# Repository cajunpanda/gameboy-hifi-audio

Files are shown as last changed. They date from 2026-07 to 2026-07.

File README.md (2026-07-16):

# GameBoy HiFi Audio

A Bluetooth audio upgrade for the Game Boy Advance. It removes the console's
stock audio amp and replaces the whole audio back end with an ESP32 and an
ES8388 codec. The mod streams game audio to Bluetooth headphones and speakers,
and it also drives the GBA's built-in speaker and wired headphone jack itself,
with onboard EQ, volume, and sound effects.

<p align="center">
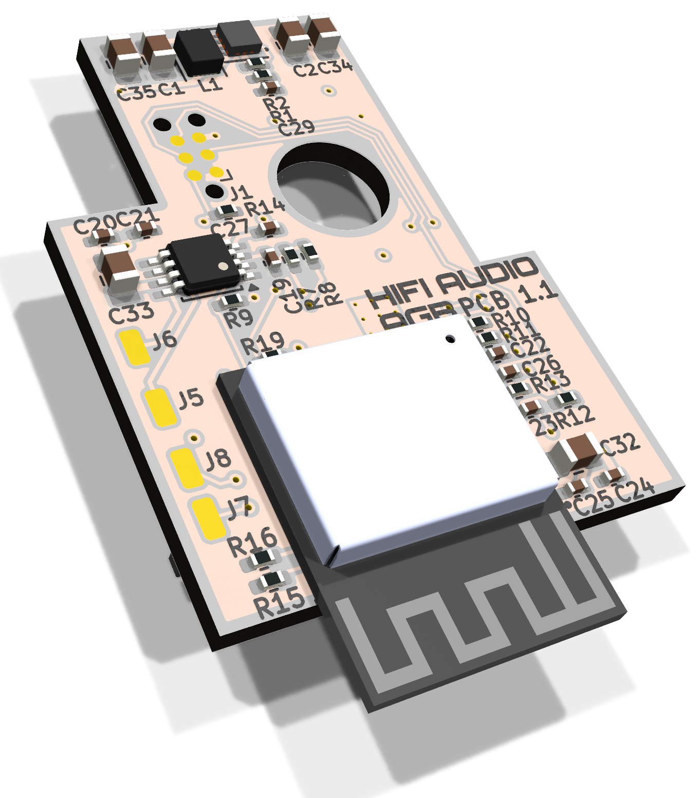
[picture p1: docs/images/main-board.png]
GameBoy HiFi AGB main board
  
  &nbsp;&nbsp;
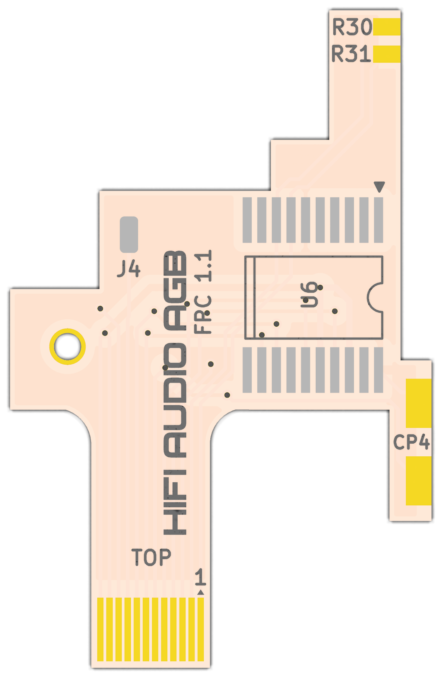
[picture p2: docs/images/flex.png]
GameBoy HiFi AGB flex
  
  <br>
  <sub>AGB main board (left) and flex (right)</sub>
</p>

What you get:

- Bluetooth (A2DP) output to any standard headphones or speaker.
- Wired headphones and the internal speaker, driven by the onboard codec.
- EQ, volume, and sound-effect cues, tunable from a phone or laptop over
  Bluetooth (no app install, it runs in the browser).
- A battery-saver mode that puts the radio and CPU to sleep and passes audio
  through the codec in analog, for long unplugged sessions.
- Firmware updates over Bluetooth.

<p align="center">
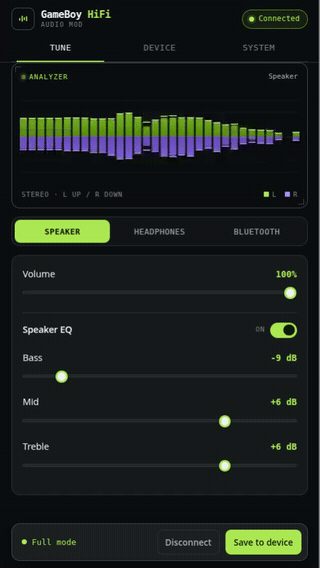
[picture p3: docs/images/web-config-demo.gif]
The web config page: live spectrum and equalizer, tuned in the browser over Bluetooth
  
  <br>
  <sub>The browser config page: a live spectrum and per-output EQ, tuned over Bluetooth with no app to install</sub>
</p>

Prebuilt, pre-assembled kits are coming soon at [cajunpanda.com](https://cajunpanda.com),
for anyone who would rather not source the parts and solder it themselves. Kits will ship
pre-flashed and update over Bluetooth, so they need no programming cable.

I am looking for beta testers interested in trying out the mod. If you want an early kit or
board, reply on the [beta testers discussion](https://github.com/cajunpanda/gameboy-hifi-audio/discussions/1)
or join the [Discord](https://discord.gg/6BNetnK6kC).

This repository currently holds the board for the original Game Boy Advance
(AGB). The firmware is shared across models. Boards for other Game Boy models
will be added under `hardware/` as they are designed.

## Pick your path

This project has three kinds of reader. Start with the doc that matches you.

- **You have a GameBoy HiFi board, or one already in your GBA.**
  [docs/AGB-INSTALL.md](docs/AGB-INSTALL.md) fits the board into a Game Boy Advance, and
  [docs/MANUAL.md](docs/MANUAL.md) covers using it: pairing, the control button,
  the modes, the web config page, and troubleshooting.

- **You want to build the boards yourself.**
  Read [docs/HARDWARE.md](docs/HARDWARE.md): the bill of materials, the KiCad
  boards, fabrication, and assembly. It links on to the install guide once the
  boards are ready.

- **You want to change the firmware.**
  Read [docs/FIRMWARE.md](docs/FIRMWARE.md): the toolchain, build and flash,
  the architecture, the config options, and how the control surfaces work.

## Repository layout

```
firmware/        ESP-IDF firmware (PlatformIO project), shared across boards
hardware/agb/    KiCad projects for the AGB main board and flex (schematic carries the BOM)
web/             Web Bluetooth config page (hosted on GitHub Pages)
tools/           make_clip.py (clip authoring), bringup.py (bench current<->boot correlation)
docs/            the guides above
```

## License

- Firmware and other source code: MIT, see [LICENSE](LICENSE).
- Hardware (schematics, board layouts, footprints): CERN-OHL-P v2, see
  [hardware/LICENSE](hardware/LICENSE).
- Documentation: CC BY 4.0, see [docs/LICENSE](docs/LICENSE).

You can build, modify, sell, and redistribute all of it, including in your own
products, as long as you keep the attribution and the license notices.

## A note on the trademark

Game Boy and Game Boy Advance are trademarks of Nintendo. This is an
independent, unofficial project and is not affiliated with or endorsed by
Nintendo.

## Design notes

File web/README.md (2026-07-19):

# Web config page

A single-file Web Bluetooth control panel for the mod's BLE config server
(`firmware/src/ble_config.c`). It tunes the DSP settings (speaker and Bluetooth
volume, EQ, sound effects), sets the R-button hold timings, plays chimes and
clips, saves to the device, and updates the firmware over the air. It also
converts a dropped audio file to a startup clip in the browser and uploads it.
No app, no WiFi, just Chrome or Edge talking to the ESP32 over Bluetooth.

## Hosting (GitHub Pages)

`.github/workflows/pages.yml` deploys this folder to GitHub Pages on every push
to `main` that touches `web/`. One-time setup: repo Settings, Pages, Source =
GitHub Actions. The page is then served at `https://<user>.github.io/<repo>/`.

Web Bluetooth needs a secure context, which the Pages HTTPS provides. For local
work, serve over localhost (for example `python3 -m http.server` in this folder).
Opening the file directly does not expose `navigator.bluetooth`.

## Use

1. Power the mod. The BLE server advertises as "GameBoy HiFi Setup" with slow
   advertising to keep current low, so discovery can take a couple of seconds.
2. Open the page, click Connect, and pick "GameBoy HiFi Setup".
3. The controls fill in from the device and push live edits back. Save to device
   persists them. Changes made from the UART console show up here through
   notifications.

On Linux, Chrome needs the experimental web platform features flag.

## Firmware update

The Firmware update card pushes a new `firmware.bin` to the device over
Bluetooth. Drop the file, click Flash firmware, and keep the page open until the
device reboots into the new image (a minute or two; audio pauses). The transfer
uses windowed flow control with a host-side crc32 and on-device SHA-256
validation before the boot slot swaps. Older firmware without the OTA
characteristics is detected, and the card disables itself.

The card shows the installed firmware version and slot from the device. The
version comes from `CONFIG_APP_PROJECT_VER` in `firmware/sdkconfig.defaults`.

## Wire format

The settings characteristic is a packed little-endian blob mirroring
`gbhifi_settings_t`. The exact layout is documented in both `web/index.html` and
`firmware/src/ble_config.c` (`SETTINGS_WIRE_LEN`); keep the two in lockstep. The
mode field is read-only status: entering Battery saver duty-cycles the radio to
sleep, so the page cannot reverse it. The R-button hold gesture owns the mode.

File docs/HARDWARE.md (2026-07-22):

# GameBoy HiFi Audio: Hardware Guide

This guide is for building the mod yourself: ordering the boards, sourcing
parts, assembling, and installing it in a Game Boy Advance. The KiCad projects
under `hardware/agb/` are the authoritative reference for the schematic, the
board layout, and the exact net and pin assignments. This document is the
overview.

This is an advanced modification. It requires removing a surface-mount chip from
the GBA mainboard, fine-pitch soldering, and reflow or hot-air work on a QFN
part. If you are not comfortable with that, have it done by someone who is.

## What is on the boards

There are two boards for the AGB:

- **Main board** (`hardware/agb/agb-hifi-audio-pcb`): the ESP32 module, the
  audio codec, the power supply, and the speaker amplifier.
- **Flex** (`hardware/agb/agb-hifi-audio-fpc`): a flexible circuit that solders
  to the GBA's audio-amp footprint and carries power, ground, the audio taps,
  and the control-button signal back to the main board. It folds over once
  during installation.

<p align="center">
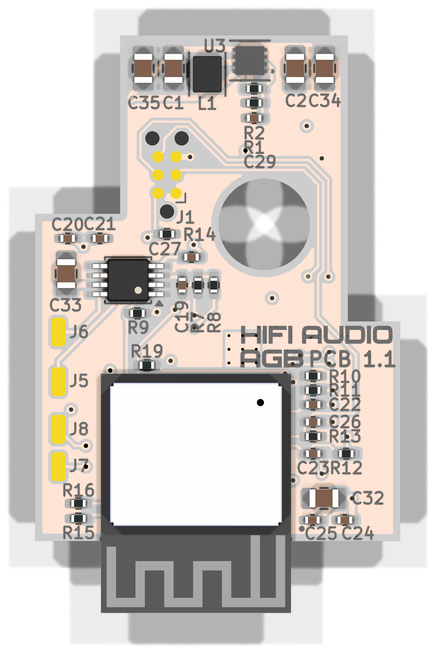
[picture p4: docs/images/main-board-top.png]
AGB main board, top
  
  &nbsp;&nbsp;
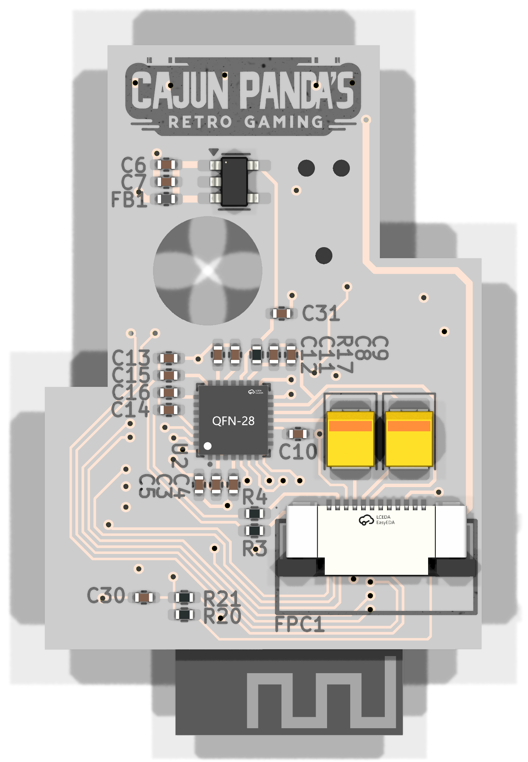
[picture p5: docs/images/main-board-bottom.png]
AGB main board, bottom
  
  <br>
  <sub>Main board, top (left) and bottom (right)</sub>
</p>

## Key parts

The bill of materials lives in the KiCad schematic itself (the source of truth),
where each symbol carries its manufacturer, LCSC, and DigiKey part numbers. Export
it from the [main-board schematic](../hardware/agb/agb-hifi-audio-pcb/). The main
active parts are:

| Ref  | Part | Function |
| ---- | --- | --- |
| U1 | ESP32-PICO-MINI-02-N8R2 | MCU, Bluetooth radio, 8 MB flash |
| U2 | ES8388 | Stereo audio codec: ADC, DAC, headphone amp, analog bypass |
| U3 | TPS61021A | Boost converter, battery to 3.3 V |
| U4 | PAM8302A | Mono Class-D amplifier for the internal speaker |
| U5 | LP5907MFX-3.0 | Low-noise LDO for the codec's analog supply |
| FPC1 | AFC07-S12ECA-00 | 12-pin flat-flex connector for the flex |

The ES8388 is a QFN-28 and is not hand-solderable in the usual sense. Plan on a
stencil and reflow, or hot air. The ESP32 module needs the same treatment: its
pads sit under the module's edge rather than as exposed castellations, so an iron
cannot reach them all. Its pitch is coarser than the codec's, so it is the more
forgiving of the two, but it is still a reflow or hot-air part.

FPC1 is a JLCPCB-stocked part (LCSC C262585). It replaced the Hirose
FH12A-12S-0.5SH, which mates the same flex but uses a different fitting-nail
land pattern, so the Hirose only fits board revisions before 1.1.

### Full bill of materials

Passives are listed by value; the schematic carries the exact manufacturer,
LCSC, and DigiKey part numbers for every line. 26 lines, 60 pieces.

| Ref(s) | Qty | Value / part | Package |
| --- | --- | --- | --- |
| C1, C2, C32–C35 | 6 | 22 µF 25 V | 0805 |
| C3, C6, C8, C10, C11, C20, C24 | 7 | 10 µF | 0402 |
| C4, C7, C9, C21, C25, C26, C30 | 7 | 100 nF | 0402 |
| C5, C15, C16, C19, C27, C31 | 6 | 1 µF | 0402 |
| C12 | 1 | 4.7 µF | 0402 |
| C13, C14 | 2 | 10 nF C0G | 0402 |
| C17, C18 | 2 | 220 µF 6.3 V (tantalum) | EIA-3528 |
| C22, C23 | 2 | 10 nF | 0402 |
| C29 | 1 | 10 pF | 0402 |
| R1 | 1 | 316 kΩ | 0402 |
| R2, R9, R20, R21 | 4 | 100 kΩ | 0402 |
| R3, R4 | 2 | 2.2 kΩ | 0402 |
| R7, R8 | 2 | 15 kΩ | 0402 |
| R10, R13, R14 | 3 | 10 kΩ | 0402 |
| R11, R12 | 2 | 1 kΩ | 0402 |
| R15, R16 | 2 | 4.7 kΩ | 0402 |
| R17 | 1 | 10 Ω | 0402 |
| R19 | 1 | 33 Ω | 0402 |
| L1 | 1 | 0.47 µH (power inductor) | 2.5 × 2.0 mm |
| FB1 | 1 | 600 Ω @ 100 MHz (ferrite bead) | 0402 |
| FPC1 | 1 | AFC07-S12ECA-00 | 12-pin FFC |
| U1 | 1 | ESP32-PICO-MINI-02-N8R2 | SMD module |
| U2 | 1 | ES8388 | QFN-28 (4 × 4 mm) |
| U3 | 1 | TPS61021A | WSON-8 (2 × 2 mm) |
| U4 | 1 | PAM8302A | MSOP-8 |
| U5 | 1 | LP5907MFX-3.0 | SOT-23-5 |

## Ordering the boards

Open the KiCad project (KiCad 10 or newer) and export fabrication data:

1. Run the design rule check and the electrical rule check first.
2. Plot Gerbers and drill files for the main board, and again for the flex.
3. Export the position (centroid) file if you are using an assembly service.

The flex needs special fabrication settings: it is a two-layer polyimide flex
with a stiffener under the connector fingers, and a few intentional edge-plated
lands. Those requirements are written into the flex board as fabrication notes
on the documentation layer, so they travel with the Gerbers. Read them before
you order, and tell the fab house it is a flex, not a rigid board.

JLCPCB and PCBWay both make these. For the main board, their assembly services
can place most of the parts, which saves you the QFN reflow.

## Power

The GBA's switched battery rail (about 2.4 V to 3.2 V) feeds the TPS61021A
boost converter, which produces 3.3 V for the ESP32, the codec's digital side,
and the speaker amp.

The codec's analog supply (AVDD, and HPVDD behind R17) is its own domain: the
3.3 V rail passes through the ferrite (FB1) into U5, an LP5907MFX-3.0 low-noise
LDO (~82 dB PSRR at 1 kHz), which regulates a quiet 3.0 V for the codec's analog
stages. It isolates the codec's DAC, mixer, and headphone amp from the boost
rail, which the Bluetooth radio's wake-up bursts modulate. Bulk caps are spread
across the rail (boost output, boost input, ESP32, speaker amp) for brown-out
margin at low battery.

## The audio source

The GBA CPU does not output a line-level analog signal. Its sound pins (S01 and
S02) are a PWM bitstream. The reconstruction that turned that into analog used
to live inside the amp chip you are removing, so the mod includes its own
reconstruction low-pass filter at the tap. The filtered signal feeds the codec's
line inputs. The codec's input range suits this signal directly, so there is no
preamp.

## Installing the mod

Once the boards are assembled, see [AGB-INSTALL.md](AGB-INSTALL.md) to fit the mod into
a Game Boy Advance: removing the stock parts, attaching the flex, wiring the
speaker, and the first firmware flash.

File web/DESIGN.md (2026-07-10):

# Design

Precision-instrument control panel for the GameBoy HiFi audio mod. A single
self-contained `index.html` (no build, no external assets) served from GitHub
Pages. Dark graphite enclosure, a phosphor-lime "signal" accent (a refined nod
to the DMG screen), violet as the stereo R-channel. Everything technical is
monospace; prose is a humanist sans.

## Theme

- Dark only (`color-scheme: dark`). **Committed** color strategy (one saturated
  signal color carries active states) on an otherwise restrained product surface.
- Metaphor: boutique audio test gear — hairline panels, corner ticks, monospace
  readouts, a live analyzer as the hero.

## Color (OKLCH)

Graphite neutral ramp (cool, hue ~200):

- `--bg` 0.165 · `--bg-2` 0.195 · `--surface` 0.216 · `--surface-2` 0.245 · `--control` 0.275
- `--line` 0.315 · `--line-2` 0.40 (hairlines, borders)
- Ink: `--ink` 0.965 · `--muted` 0.755 · `--faint` 0.605

**Signal — phosphor lime** (the one hot accent: active states, values, primary
actions):

- `--signal` 0.865 0.19 129 · `--signal-2` 0.80 · `--signal-dim` 0.60 · `--signal-soft` (15% signal)
- `--signal-ink` 0.20 0.04 130 — near-black text on lime fills (buttons, toggles, active segment)

**Violet — stereo R-channel + secondary:** `--violet` 0.64 0.19 292 · `--violet-2` 0.72

Semantic: `--warn` 0.82 0.14 82 · `--danger` 0.66 0.19 25. The Connected / OK /
Full-mode states reuse signal lime; Battery saver uses warn amber.

Contrast: body and labels sit at `--muted` / `--ink` on graphite (≥ 4.5:1); lime
and violet are used at high L for values and large text; near-black on lime for
button text.

## Typography

Two families on a **contrast axis (monospace vs humanist)** — no external fonts:

- `--font-sans` = `system-ui` stack — prose, control labels, headings, help text.
- `--font-mono` = `ui-monospace` stack — wordmark, section nav, every numeric
  readout (dB / % / ms), status pill, and equipment micro-labels.

Rationale: monospace *is* the instrument voice, and the mono/sans split carries
the hierarchy, so no display font is needed (preserves the single-file, offline
constraint). Fixed rem scale with tight ratios (product register).

Equipment **micro-labels** (`.label-mono` and the analyzer/output labels): mono,
uppercase, 0.11em tracking, `--faint`. These are diegetic gear labeling (analyzer
header, L/R legend, unit hints) — deliberately *not* the tracked-uppercase
marketing eyebrow anti-pattern.

## Layout — responsive app console

- Content max-width ~46rem. Breakpoint at **820px**.
- **Desktop (≥ 820px):** two-pane grid. A 15rem left **rail** (wordmark +
  `AUDIO MOD`, vertical Tune/Device/System nav with a lime active dot, and a
  pinned footer: mode chip · Save to device · Disconnect) beside a scrolling
  **main** pane led by the analyzer.
- **Mobile (< 820px):** the rail dissolves via `display: contents`. Its top block
  becomes a sticky top bar (wordmark + status pill + underline tab nav); its
  footer becomes a floating **fixed bottom action bar** (mode · Disconnect ·
  Save), with the "Saved ✓" confirmation floating above it.
- Container queries adapt inner grids (e.g. R-button hold timings go 2-up on
  wider main).

## Components

- **Spectrum analyzer (hero):** bordered instrument panel with corner ticks, an
  `ANALYZER` header + live dot + source label, a canvas stereo meter (lime L up /
  violet R down, gradient bars, slow-decay peak caps, faint dB gridlines, a 0 dB
  center line) and an L/R legend. DPR-scaled. Auto-labels and follows the live
  audio source.
- **Output segmented control:** 3-up Speaker / Headphones / Bluetooth; active =
  lime fill + near-black text. Drives which single EQ + volume shows — one
  contextual EQ, not three stacked.
- **Sliders:** thin graphite track, ink thumb ringed in lime, mono value readout
  in lime. EQ bands dim via `:has()` when that EQ is bypassed.
- **Toggles:** graphite off → lime on (near-black knob).
- **Buttons:** primary = solid lime + near-black text; ghost = outline. Flat — no
  gradient, no glow.
- **Status pill / mode chip:** mono; lime when Connected / Full mode, amber for
  Battery saver.
- **Cards:** graphite surface, hairline border, sentence-case titles (no
  eyebrows). Firmware/OTA drop zone, device console (mono), diagnostics/activity
  log.
- **Links:** lime, underlined.

## Motion

- 150–250 ms, state-conveying only. View Transitions crossfade section switches;
  a short staggered entrance plays once on connect.
- The analyzer runs on `requestAnimationFrame` (fast-attack / slow-decay
  smoothing + peak decay).
- `prefers-reduced-motion`: animations and transitions collapse to instant; view
  transitions disabled.

## Constraints

- Single self-contained `index.html`; inline CSS/JS; **no build step, no external
  requests** (CSP-safe, offline-friendly, forkable). Deployed to GitHub Pages via
  `.github/workflows/pages.yml`.
- Web Bluetooth only (Chrome/Edge desktop/Android; iPhone via a Web BLE browser
  app such as Bluefy or BLE-Link). All state comes from the BLE config server;
  no persistence beyond the device.

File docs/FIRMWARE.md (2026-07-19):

# GameBoy HiFi Audio: Firmware Guide

This guide is for building, flashing, and modifying the firmware. The firmware
is shared across all board models.

## Toolchain

The firmware is an ESP-IDF project built through PlatformIO, not through
`idf.py`. You need:

- PlatformIO (the `pio` CLI, or the VS Code extension).
- A Tag-Connect TC2030 serial cable for the first cabled flash. The
  [TC2030-NL-FTDI-C232HD](https://www.tag-connect.com/product/tc2030-nl-ftdi-c232hd-ddhsp-0-dtr-usb-to-tc2030-no-legs-serial-cable)
  carries DTR for auto-reset into the bootloader. Later updates go over Bluetooth.

PlatformIO downloads the ESP-IDF framework and the managed components on the
first build. `firmware/sdkconfig.defaults` is the source of truth for the IDF
configuration; the generated `sdkconfig.prod` is not checked in and is
recreated from the defaults.

## Build, flash, monitor

All firmware commands run from inside `firmware/`:

```sh
cd firmware
pio run                          # build
pio run -t upload                # flash over serial
pio run -t upload -t monitor     # flash and open the serial monitor
pio run -t menuconfig            # IDF menuconfig (edits the generated sdkconfig)
pio device monitor               # serial monitor only (115200 8N1)
```

The build output is `.pio/build/prod/firmware.bin`.

### Recommended: benchmux for iterating

For a build-flash-watch loop, [benchmux](https://github.com/cajunpanda/benchmux) is more
convenient than the raw `pio` commands. It owns the serial port and tees output to a shared
logfile, so it flashes without stopping the monitor, the boot log for the new firmware
streams straight into the log you are already watching, and you can follow that log from any
terminal. It also flashes over BLE. Install it per its README, then from `firmware/`:

```sh
serial_proxy.py monitor --port FTDI &    # own the port, stream to /tmp/serial_proxy.log
serial_proxy.py tail                     # follow the log (from any terminal)
serial_proxy.py flash --env prod         # build + upload without stopping the monitor
serial_proxy.py flash --env prod --fs    # also flash the LittleFS clip image
serial_proxy.py send get                 # inject a console command through the monitor
```

`--fs` flashes the LittleFS clip image that a plain upload skips (see "Partitions and the
clip image"), so a `firmware/data/` change needs no separate esptool step. The commands run
once and exit with a status code, which also makes benchmux a good fit for driving the board
from an editor task or an AI coding agent.

If you change `sdkconfig.defaults`, delete `sdkconfig.prod` to force it to
regenerate. Adding a new `CONFIG_*` symbol in `Kconfig.projbuild` also needs
that delete plus a rebuild, otherwise the build reports the symbol as
undeclared.

`pio run -t upload` flashes only the app. It does not write the LittleFS clip
image, so a change under `firmware/data/` needs a separate filesystem flash (see
"Partitions and the clip image" below).

## Configuration

Project options live in `firmware/src/Kconfig.projbuild` under the
"GameBoy HiFi Audio" menu. Reach them with `pio run -t menuconfig`. The groups:

- **Timeouts and timing**: standby and reconnect timing, the silence detector,
  the R-button hold thresholds, debounce, pairing and wake-hold times, and the
  factory-reset hold.
- **BLE GATT config server**: enables the Web Bluetooth control surface.
- **Speaker DSP defaults**: first-boot seed values for volume, the three EQ
  profiles (speaker, headphone, Bluetooth), and the sound cues. These are only
  the initial seeds; live values persist in NVS and are tuned at runtime.
- **Operating modes**: the default mode at boot, and what happens on a wired
  headphone unplug while in Battery saver.
- Two debug toggles: per-second ADC peak logging, and a one-shot waveform dump
  over UART.

## Partitions and the clip image

`firmware/partitions.csv` defines an 8 MB layout with two OTA app slots (so the
firmware can update itself over Bluetooth), an NVS area for settings and
Bluetooth bonds, and a LittleFS `storage` partition for sound clips.

`pio run -t upload` flashes only the app. It does not flash the LittleFS clip
image, so a plain flash leaves whatever clips were already on the board. The
build bakes `firmware/data/` into a `storage.bin` image (the `src/CMakeLists.txt`
`littlefs_create_partition_image(... FLASH_IN_PROJECT)` line owns the exact
fs-size / block-size / name-max the firmware mounts with). To (re)load the clips,
build and write that image to the `storage` partition offset:

```sh
pio run                                              # bakes .pio/build/prod/storage.bin
esptool.py write_flash 0x420000 .pio/build/prod/storage.bin
```

The `storage` offset (`0x420000`) comes from `partitions.csv`; the generated
`flasher_args.json` lists it too.

The first flash on a fresh board must be a full cabled flash: bootloader,
partition table, app into the first slot, an erased otadata, and the clip image.
After that, updates can go over Bluetooth.

The clips themselves are in the GSFX format. Use `tools/make_clip.py` to author
them: `from-wav` converts a 16-bit WAV to a clip (downmix + optional resample),
or `gen-startup` generates a synth test cue.

The boot chime plays over a muted passthrough (see "Init order"). Which clip it
uses comes from the `startup_mode` setting, whose values are `startup_mode_t` in
`settings.h`:

| mode | clip | notes |
| --- | --- | --- |
| `STARTUP_MODERN` | `startup-modern.gsfx` | the Switch/NSO version, the default |
| `STARTUP_ORIGINAL` | `startup-original.gsfx` | the full original GBA chime |
| `STARTUP_CUSTOM` | `startup-custom.gsfx` | ships with a default; replaced by a web-UI upload |
| `STARTUP_OFF` | none | no clip; the live GBA chime plays through |

`STARTUP_OFF` is not `STARTUP_ORIGINAL`. The codec and amp are still coming up
during the GBA's first ~0.9 s, so the passthrough chime is truncated. That is why
the mod voices its own clip.

All three clips ship in the filesystem image. To change one, author a new
`firmware/data/startup-*.gsfx` and reflash the image (see "Partitions and the
clip image").

The web config page can also replace `startup-custom.gsfx` over BLE. It converts
a dropped audio file to GSFX in the browser, then streams it over the same
OTACTL/OTADATA characteristics a firmware update uses (opcodes `CLIP_BEGIN` /
`CLIP_END`). The device writes to a temp file and renames it into place only once
size, CRC32 and the GSFX header check out, so a dropped link leaves the previous
clip intact. A filesystem reflash restores the bundled default.

## Source layout

```
firmware/src/
  main.c            app_main and the boot/init order
  pinmap.h          every PIN_* macro (the single source of truth for GPIOs)
  es8388.{h,c}      codec driver over I2C: power-up, mode, routing, volume
  i2s_codec.{h,c}   full-duplex I2S master to the codec (MCLK from the ESP32)
  audio_pipeline.{h,c}  ADC capture, int16 conversion, DSP, BT stream, DAC fan-out
  dsp.{h,c}         EQ, volume, and cue mixing for the speaker and BT paths
  settings.{h,c}    runtime-tunable parameters, NVS-backed, the control seam
  sfx.{h,c}         cue player: synth cues and clips streamed from LittleFS
  fs.{h,c}          LittleFS mount for the clip store
  console.{h,c}     UART REPL control surface
  ble_config.{h,c}  BLE GATT config server (drives the web page)
  bt_a2d.{h,c}      Bluedroid wrapper: connect, pair, media, bonds, events
  buttons.{h,c}     debounced ISR for the control button and HP-detect
  app_sm.{h,c}      the state machine, speaker-amp gating, and sleep policy
```

## Architecture

### Audio path

The GBA sound pins (S01/S02) are a PWM bitstream. A reconstruction low-pass
filter on the board turns that into analog, which feeds the codec line inputs.
From there:

```
codec ADC -> ESP32 (I2S RX) -> int16 stereo -> DSP -> split:
  Bluetooth:  stream buffer -> A2DP SBC encoder -> radio
  Local:      codec DAC -> headphone amp (jack) and line out -> speaker amp
```

The pipeline is fixed at 44.1 kHz interleaved stereo, 16-bit. The IDF A2DP
source endpoint hard-codes that SBC format and rejects attempts to change it, so
the sample rate, channel count, and bit depth across the codec, the I2S bus, and
the pipeline all exist to feed that fixed sink. Do not change one without the
others.

### Clocking

The ESP32 is the I2S master. It generates MCLK (from the APLL on GPIO0), BCLK,
and LRCK, and the codec is the slave. One clock domain serves both directions,
so there is no asynchronous resampling.

### Init order

`app_main` is ordered to get **audio out as fast as possible** and to keep the
Bluetooth radio off the Game Boy power-on chime. The mod boots on the GBA's
switched rail, so every power-cycle re-runs this and the chime is the first thing
the user hears.

The sequence: log the wake cause and gate a button wake, boot-mute the speaker
amp, init NVS, bring up the I2S clocks and then the codec over I2C. As soon as the
codec is configured, `app_sm_speaker_early_on()` samples HP-detect and unmutes the
speaker amp (only if no headphones are plugged) — well before the state machine
would otherwise. Then the DSP subsystem comes up: `app_sm_prime_volume()` seeds
the speaker volume from the wheel *before* `dsp_init()` reads it (so a wheel-down
user doesn't get a default-volume blare), and the local EQ profile is seeded from
the sampled HP state. The startup chime is then triggered — `dsp_begin_intro()`
mutes the live passthrough while `sfx_trigger_clip("startup")` plays the mod's own
clean, complete chime (so it isn't doubled with the truncated live GBA chime the
codec misses during boot); this is gated so a future setting can disable it and
let the GBA's own chime through. The audio pipeline and buttons start, and the
pending OTA image is confirmed good.

Only then comes Bluetooth, deliberately last among the heavy loads: `app_main`
waits until `CONFIG_GBHIFI_BT_START_DELAY_MS` after power-on **and** until the
startup chime has fully drained (`sfx_cue_active()`, capped so a wedged cue can't
block BT), parks the speaker amp (`app_sm_amp_radio_quiet()`) across the radio
window, then runs `bt_a2d_init()` (controller + radio) and the BLE config server.
This serialization exists because the radio bring-up is the largest, fastest
current step of the whole boot and on a low battery it can sag the boost rail
below the brownout threshold. Three more pieces of that guard live in firmware:

- `CONFIG_ESP_PHY_RF_CAL_NONE=y` (sdkconfig.defaults) — skips the boot-time
  partial RF calibration TX bursts and runs from NVS-stored cal data. Caveat:
  the first boot after an NVS erase runs a *full* cal (bigger spike), where the
  loop breaker below is the safety net.
- **BR/EDR TX capped at -3 dBm right after controller enable** (bt_a2d.c), so
  inquiry/page bursts never run at the +9 dBm default; the CONNECTED handler
  re-asserts the same level per link.
- **Brownout loop breaker** (main.c): an RTC-noinit magic word is armed around
  the radio bring-up and cleared on success. A boot that starts with reset
  reason BROWNOUT while armed knows the radio killed it: the first strike
  retries after a 2 s settle, two consecutive strikes skip BT for that boot and
  come up LOCAL_ONLY (chime + local audio always play instead of a reboot
  loop). A real power cycle scrambles RTC noinit and re-arms BT. All public
  `bt_a2d_*` calls no-op safely on a BT-skipped boot.

This sequence cold-boots cleanly down to a 2.0 V rail, below any usable 2xAA
level. Finally the factory-reset check, the state machine, and the console start.
The order matters; read the comments in `main.c` before reordering anything.

There is no codec read-back verify pass: the production PCB's series-R + short
MCLK routing keep the I2C config writes clean, so `es8388_init()` alone is enough.

### State machine

`app_sm.c` is the only place that owns device state. Button events, Bluetooth
events, audio silence edges, and timers all fold into one FreeRTOS queue drained
by a single task, so there are no cross-task races on the state. It also owns
the speaker-amp mute policy and the sleep policy.

The audio pipeline and the Bluetooth wrapper are isolated from each other and
from the state machine. They publish events through callbacks, and the state
machine is the only subscriber. Keep that boundary: do not add direct calls
between modules.

### Real-time threading

The real-time audio tasks are pinned to core 1, off the Bluetooth controller
core, or A2DP streaming gets garbled when the controller preempts a shared core.
Tickless idle is off for the same timing reason. There is no per-sample `sinf`
or `expf` in the audio task; the DSP uses lookup tables.

## Settings and control surfaces

`settings.c` is the single source of truth for runtime-tunable parameters
(volumes, the EQ profiles, the cues, the mode preferences, the hold times). It
is thread-safe, NVS-backed, and versioned, with a generation counter so the DSP
recomputes coefficients only when something changes.

Control surfaces only ever call the `settings_*` and `sfx_*` API. They never
touch the audio path. There are two:

- **The UART console** (`console.c`): a REPL for bring-up and tuning.
- **The BLE config server** (`ble_config.c`): the same API exposed over
  Bluetooth for the web page.

### Console commands

```
vol <0-100>          speaker volume
volbt <0-100>        Bluetooth volume
eq on|off [b m t]    speaker EQ
eqhp on|off [b m t]  headphone EQ
eqbt on|off [b m t]  Bluetooth EQ
sfx on|off [level]   cue mixing
chime [name]         play a synth cue
play <name>          play a clip
bt connect|pair      drive BT like the button (page bonds / inquiry-pair)
mode a|b             set operating mode (a = bypass/battery, b = DSP)
unplug stay|b        behavior on HP unplug in Mode A
hold [c p m e]       R-button hold thresholds, ms
wheel on|off         VOL wheel drives volume
ls                   list the clip store
save                 persist settings to NVS
get                  show current settings
```

There are also a few bench helpers (`out1`, `out2`, `outvol`, `codecmode`,
`hp`, `sleep`) for hardware bring-up.

## Web config page

`web/index.html` is a single static page that talks to the BLE config server
over Web Bluetooth. There is no build step and no backend. It is published to
GitHub Pages by `.github/workflows/pages.yml` on any push that touches `web/`.
Web Bluetooth needs a secure context, which the Pages HTTPS provides. The page
reads and writes the settings, uploads clips, and pushes firmware updates.

The System tab mirrors the UART REPL: it streams the device log and takes the
same console commands (`help`, `get`, `batt`, `nr`, ...), so you can watch and
poke a running board over BLE with no cable.

<p align="center">
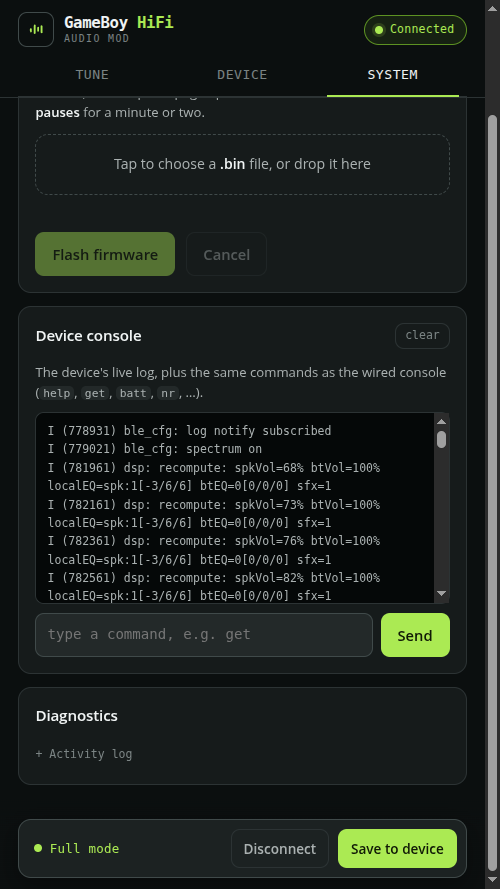
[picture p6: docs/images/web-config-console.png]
The System tab device console: live log and command input over BLE
  
  <br>
  <sub>The System tab's device console: the live log and the same commands as the wired console, over Bluetooth.</sub>
</p>

## OTA updates

The firmware can update itself over Bluetooth. The web page pushes a new
`firmware.bin` to the BLE OTA characteristics; the device writes it to the
inactive app slot, verifies it, swaps the boot slot, and reboots. If a fresh
image fails to finish booting, the bootloader rolls back to the previous slot.
The running image confirms itself good only after init completes without a
panic.

## Board targets

The build targets the ESP32-PICO-MINI-02-N8R2 module (8 MB flash) on the
production board. `pinmap.h` holds every GPIO assignment and is the single source
of truth for pins; the flash size and partition table are set in
`sdkconfig.defaults` and `partitions.csv`. There is one PlatformIO env, `prod`,
so the build output is always `.pio/build/prod/firmware.bin`.

To bring the firmware up on a different ESP32 module (for example a dev board on
the bench), add a PlatformIO env and adjust the GPIO values in `pinmap.h`, which
is the only file the pin map lives in.

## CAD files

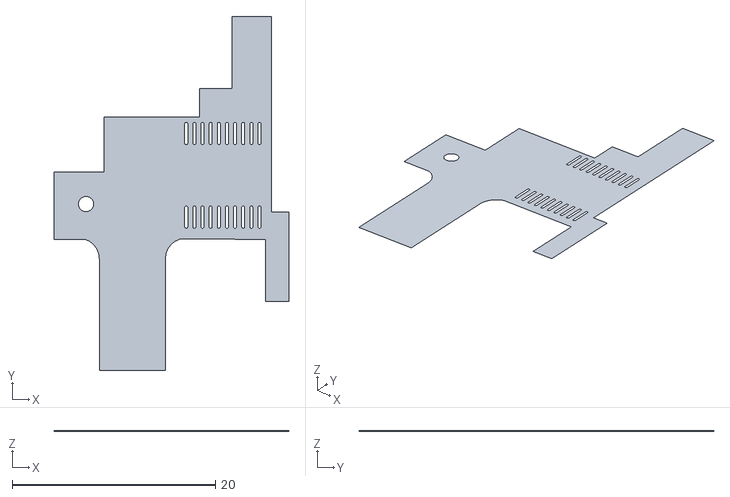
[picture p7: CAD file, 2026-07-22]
hardware/agb/agb-hifi-audio-fpc/agb-hifi-audio-fpc.stl
23.1 x 34.8 x 0.025

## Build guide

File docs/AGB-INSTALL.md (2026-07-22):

# GameBoy HiFi Audio: AGB Installation Guide

This guide covers fitting a GameBoy HiFi board into a Game Boy Advance: removing
the stock parts, soldering on the flex, wiring the speaker, and the first
firmware flash. You need an assembled main board and flex, either from a kit or
built and assembled per [HARDWARE.md](HARDWARE.md).

This is an advanced modification. It involves removing surface-mount parts from
the GBA mainboard and fine-pitch soldering. If you are not comfortable with that,
have it done by someone who is. The changes are permanent: the mod becomes the
console's audio system.

## Video walkthrough

A video of the flex install, start to finish. Watch it before you begin, then
follow the written steps below as you work.

<p align="center">
  <a href="https://youtu.be/mPUGNb_kJ9I">
    Watch: Game Boy Advance HiFi Audio Mod Flex Install
  </a>
</p>

## What you need

- An assembled main board and flex.
- A hot-air station (recommended), or a low-melt desoldering alloy such as
  Chipquik, for lifting U6 and CP4 cleanly.
- A fine-tip soldering iron, flux, and fine solder.
- A Tag-Connect TC2030 serial cable for the first flash, only if you assembled
  the board yourself (see First firmware flash below). Prebuilt kits ship
  pre-flashed and need no cable.
- GBA opening tools (a tri-wing driver for the shell).

## Remove the stock parts

Open the GBA and take out the mainboard. Then remove these parts from it:

- U6, the stock audio amplifier.
- CP4, the coupling caps.
- R30 and R31.
- The speaker.

Use hot air to lift U6 and CP4. If you do not have hot air, flood their pins with
a low-melt alloy (Chipquik or similar) and lift them with the iron. Work
carefully: the flex solders back onto these same footprints, so keep the pads
clean and intact. R30, R31, and the speaker come off with a regular iron.

<!-- photo: U6, CP4, R30, R31, and the speaker removed -->

## Solder on the flex

The flex solders to the freed footprints: U6, CP4, R30, R31, and the speaker
pads. That is how the mod picks up power, ground, the audio taps, the headphone
sleeve return, and the R-button net, and it anchors the flex at the speaker
holes.

Solder the flex exactly per its silkscreen and the KiCad flex project. Follow
that pad mapping, not a generic pinout.

### Tapping the CPU audio (two ways)

The two audio signals (the CPU sound pins S0 and S1) can reach the flex by either
route. Pick whichever you find easier; the result is electrically the same.

- **At the R30 / R31 pads (default).** The flex lands solder directly onto the
  R30 and R31 footprints. These are small pads right at the flex edge, so this is
  the fiddliest joint of the whole install.
- **Through the U6 footprint (alternative).** Bridge across each of the R30 and
  R31 footprints with a short length of fine wire, so the audio passes straight
  through to the U6 footprint. The flex then picks S0 and S1 up at the U6 pads
  (where it already solders), and nothing has to land on the tiny R30 / R31 flex
  lands.

If an S0 or S1 pad lifts or is damaged while you remove the stock parts, bridge
from it to the nearby S0 / S1 via instead. It is the same net, so the tap still
works.

<!-- photo: flex soldered onto the footprints -->

## Connect the boards and the speaker

1. Connect the flex to the main board through the flat-flex connector.
2. Reattach the GBA's own speaker — the one you removed from the mainboard — to
   the mod PCB's `SPK+` / `SPK-` pads, not back to the GBA mainboard. The mod's
   own amplifier drives it.
3. Fold the flex as designed and secure the main board inside the shell.

<!-- photo: flex connected, speaker wired, board secured -->

## First firmware flash

Prebuilt kits ship pre-flashed. If you bought one, skip this step and update over
Bluetooth from the web config page.

A board you assembled yourself has no firmware. Flash it once through the board's
Tag-Connect serial port, then later updates go over Bluetooth. The recommended
cable is the [Tag-Connect TC2030-NL-FTDI-C232HD](https://www.tag-connect.com/product/tc2030-nl-ftdi-c232hd-ddhsp-0-dtr-usb-to-tc2030-no-legs-serial-cable),
which carries the DTR line so the flasher can reset the board into the bootloader
on its own.

See [FIRMWARE.md](FIRMWARE.md) for the build and flash steps.

## After installation

Reassemble the console and power it on. The mod runs off the GBA's battery rail,
so it starts with the console. See [MANUAL.md](MANUAL.md) for pairing, the
control button, and the operating modes.

## Cautions

- Removing U6 and CP4 is permanent. The mod becomes the GBA's audio system.
- Desolder U6 and CP4 with hot air or a low-melt alloy so you do not lift their
  pads; the flex reuses those footprints.

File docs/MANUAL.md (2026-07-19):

# GameBoy HiFi Audio: User Manual

This guide is for using a Game Boy Advance that has the mod installed. If the mod
is not installed yet, see [AGB-INSTALL.md](AGB-INSTALL.md) first. To build the boards
yourself, see [HARDWARE.md](HARDWARE.md).

## What it does

The mod replaces the GBA's audio amplifier with a small board built around an
ESP32 and an audio codec. Once it is installed:

- Game audio streams to Bluetooth headphones or a Bluetooth speaker.
- The GBA's own speaker and headphone jack still work, and they sound better,
  because the board runs the audio through an equalizer and a proper headphone
  amp.
- You can adjust the sound from a phone or laptop over Bluetooth, in the
  browser, with no app to install.

The board is powered from the GBA's battery rail, so it turns on and off with
the console. There is no separate switch.

## The control button

There is one control: the right shoulder button (R). It does double duty. In
games it works as the normal R button, and a quick tap never triggers anything
on the mod. To control the mod you press and hold it.

While you hold R, the device plays a short chime each time you cross a step.
Let go on the step you want:

- Hold about 3 seconds (one chime): connect to your saved headphones.
- Hold about 6 seconds (second chime): enter pairing mode for a new device.
- Hold about 9 seconds (third chime): switch between Full mode and Battery
  saver.

If you hold past a step you do not want, just keep holding to the next one. If
you let go before the first chime, nothing happens.

These hold times can be changed from the web config page if the defaults do not
suit you.

## Pairing your first headphones

1. Turn on the GBA.
2. Put your Bluetooth headphones or speaker into their own pairing mode.
3. Hold R until you hear the second chime (about 6 seconds), then let go. The
   mod is now searching.
4. When it finds your headphones it connects and plays a confirmation chime.

The mod remembers what it paired with, but it does not turn Bluetooth on by
itself. When you turn the GBA on it starts up quietly on the speaker and wired
jack and waits for you. To connect your saved headphones, hold R until the first
chime (about 3 seconds) and let go; it reconnects and plays a confirmation
chime. You only use pairing (the second chime) when you want to add a new
device.

If you have paired more than one device, the first chime tries the most recently
used one first, then cycles through the others.

Once you are connected, a brief dropout fixes itself. If the headphones go out
of range or you turn them off and on, the mod reconnects on its own. It only
gives up, and waits for you to hold R again, if it cannot get them back after a
short while.

If you prefer the mod to reconnect to your saved headphones automatically the
moment you power on, that is available as a saved option. It is off by default so
the radio stays quiet until you ask for it.

## Wired headphones and the speaker

Plug headphones into the GBA's headphone jack and the internal speaker mutes
automatically, the same as a stock console. Unplug them and the speaker comes
back. The board drives the wired jack directly, so wired headphones work even
when nothing is paired over Bluetooth.

## Volume

Use the GBA's volume wheel as usual. It sets the volume for the speaker and the
wired jack. Bluetooth headphones have their own volume control; use that for
Bluetooth listening.

## Full mode and Battery saver

There are two operating modes.

- **Full mode** is the default. It runs the equalizer and sound effects, and it
  streams to Bluetooth. This is the mode you want most of the time.
- **Battery saver** passes the audio straight through in analog and puts the
  processor and radio to sleep between adjustments. It plays through the speaker
  and wired headphones only. The equalizer, sound effects, and Bluetooth
  streaming are paused while it is on. Use it for long sessions when you are
  listening on the speaker or wired headphones and want the most battery life.

Switch between them by holding R to the third chime (about 9 seconds) and
letting go. This works at any time, including while the mod is searching for
headphones: switching to Battery saver stops the search right away and does not
make you wait. In Battery saver there is no chime menu, so to leave it just hold
R for about 9 seconds; the equalizer audio coming back and a chime tell you it
switched.

## Battery life

The mod runs off the GBA's battery rail, so it adds to the console's draw. The
current column below is the extra draw the mod puts on the battery, measured at
the battery terminals; it shifts a little with pack voltage. The runtimes are
rough figures on a fresh pair of AA alkaline cells, listening on the speaker.

| What you are doing | Extra current from the mod | Runtime |
| --- | --- | --- |
| Full mode, local speaker/headphones | ~80 mA | ~13 hours |
| Battery saver, local speaker/headphones | ~30 mA | ~14 hours |
| Bluetooth streaming | ~200 mA | ~9 hours |

Bluetooth is by far the heaviest mode, because the radio draws current in bursts;
if you are not using it, Full mode on the speaker or wired jack lasts much longer,
and Battery saver stretches it a little further still.

These figures are for a stock GBA. If your console has a backlit **IPS screen
mod**, the backlight draws more than the audio mod does, and it roughly halves
every number above (expect about 5 hours of Bluetooth streaming). Turning the
screen brightness down is the most effective way to get that time back.

## The web config page

The config page runs in your browser and talks to the mod over Bluetooth, so it
works from a phone or a laptop with no install. It needs a browser that
supports Web Bluetooth (Chrome or Edge on Android, Windows, macOS, or Linux;
Web Bluetooth is not available in Safari or on iOS).

Open the page:

```
https://cajunpanda.github.io/gameboy-hifi-audio/
```

Then:

1. Turn on the GBA so the mod is running.
2. Click Connect and pick **GameBoy HiFi Setup** from the list.
3. The controls fill in with the current settings. Changes apply live as you
   move them.
4. Click Save to device to keep the changes after a power cycle.

<p align="center">
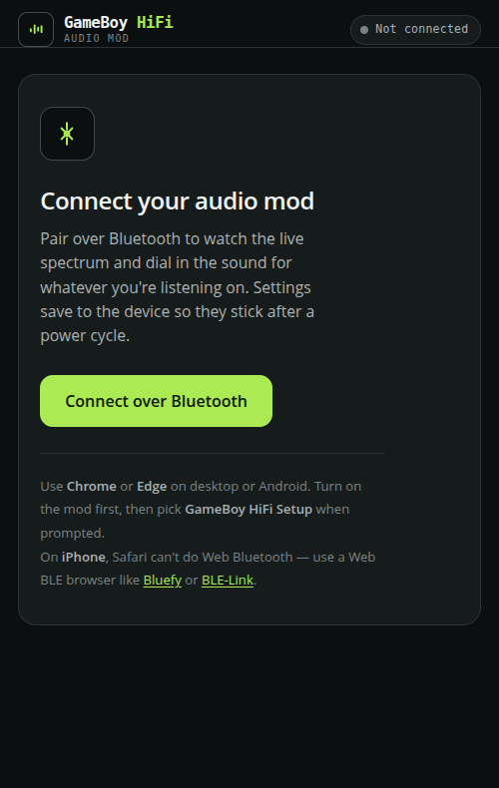
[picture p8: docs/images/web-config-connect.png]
The connect screen
  
  &nbsp;&nbsp;
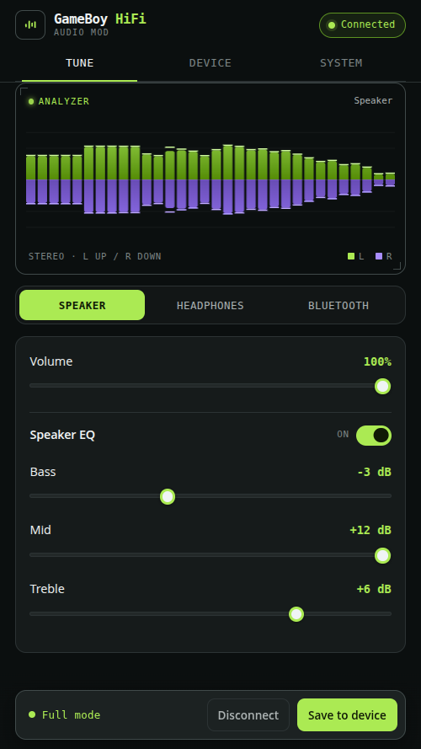
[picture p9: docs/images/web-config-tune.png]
The Tune tab, with a live spectrum and the speaker equalizer
  
  <br>
  <sub>Connect over Bluetooth (left). Once paired, the Tune tab shows a live spectrum and the equalizer (right).</sub>
</p>

The equalizer updates as you drag it, so each change is audible right away:

<p align="center">
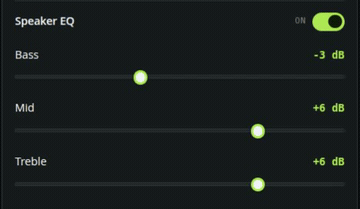
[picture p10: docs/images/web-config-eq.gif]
Dragging the bass, mid, and treble sliders
  
  <br>
  <sub>Bass, mid, and treble, each adjustable live.</sub>
</p>

From the page you can set:

- Speaker volume and Bluetooth volume.
- Equalizer (bass, mid, treble) for the speaker, for wired headphones, and for
  Bluetooth, each on its own.
- Sound effect cues and their level.
- The startup sound: the modern Switch version, the original Game Boy Advance
  chime, your own, or off. Off lets the console's own chime through, which
  starts a moment late because the mod is still waking up.
- Your own startup sound: drop in an MP3, M4A, WAV, OGG or FLAC and the page
  converts the first 4 seconds and sends it over Bluetooth.
- The R-button hold times.
- Firmware updates: push a new firmware file to the mod over Bluetooth. Keep
  the page open until it reboots. Audio pauses for a minute or two during the
  update.

<p align="center">
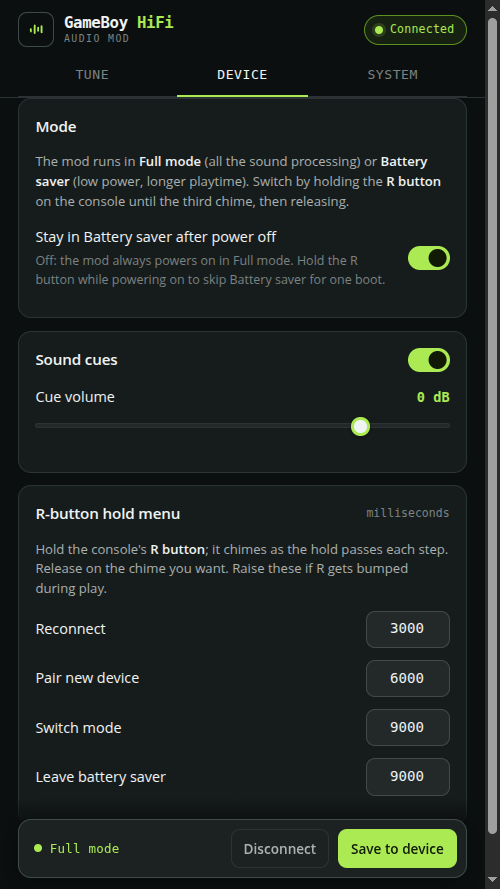
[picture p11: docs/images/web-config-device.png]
The Device tab: modes, sound cues, and R-button hold times
  
  &nbsp;&nbsp;
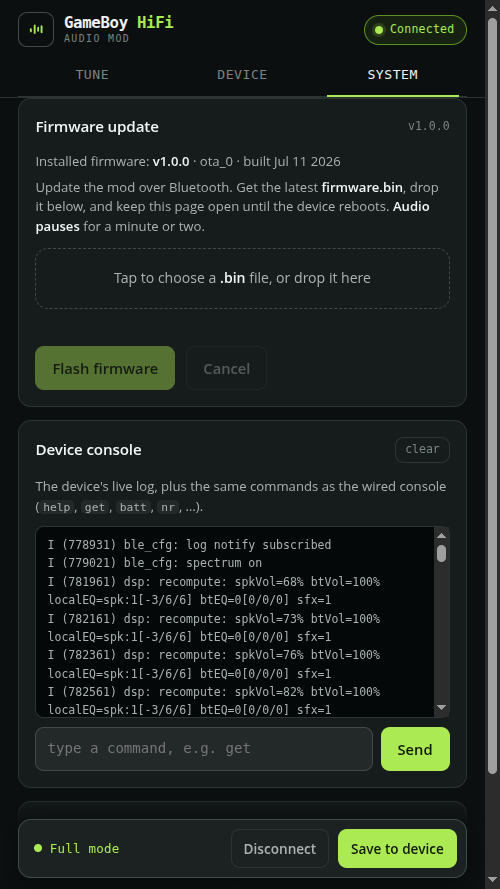
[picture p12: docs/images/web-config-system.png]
The System tab: firmware updates and the device console
  
  <br>
  <sub>Device tab: modes, sound cues, and the R-button hold times (left). System tab: firmware updates (right).</sub>
</p>

## Factory reset

To erase all paired devices, hold R while you turn the GBA on and keep holding
for about 10 seconds. The next time you pair, the device list starts fresh.

## Troubleshooting

**It will not connect to my headphones.**
Put the headphones in pairing mode first, then hold R to the second chime to
search. If it still fails, do a factory reset and pair again.

**It does not reconnect by itself when I turn the GBA on.**
That is normal. The mod waits for you so the radio stays quiet until you want it.
Hold R to the first chime (about 3 seconds) to reconnect your saved headphones.
If you would rather it reconnect automatically at power-on, that can be turned on
as a saved option.

**No sound from Bluetooth.**
Check that you are in Full mode, not Battery saver. Battery saver does not
stream over Bluetooth. Hold R to the third chime to switch.

**No sound from the speaker.**
Make sure nothing is plugged into the headphone jack. The speaker mutes
whenever a plug is detected.

**The web page does not see the device.**
Use Chrome or Edge. Make sure the GBA is on. The mod advertises as
"GameBoy HiFi Setup". If a previous browser tab is still connected, close it
first; only one connection at a time is allowed.

**It paired but keeps dropping.**
Weak battery can cause dropouts because the radio draws current in bursts. Try
fresh or freshly charged batteries.

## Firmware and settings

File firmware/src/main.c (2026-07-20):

#include <inttypes.h>

#include "freertos/FreeRTOS.h"
#include "freertos/task.h"
#include "esp_attr.h"
#include "driver/gpio.h"
#include "driver/rtc_io.h"
#include "esp_app_desc.h"
#include "esp_err.h"
#include "esp_log.h"
#include "esp_ota_ops.h"
#include "esp_sleep.h"
#include "esp_timer.h"
#include "esp_system.h"
#include "nvs_flash.h"

#include "sdkconfig.h"

#include "app_sm.h"
#include "audio_pipeline.h"
#include "ble_config.h"
#include "bt_a2d.h"
#include "buttons.h"
#include "console.h"
#include "dsp.h"
#include "es8388.h"
#include "fs.h"
#include "i2s_codec.h"
#include "pinmap.h"
#include "settings.h"
#include "sfx.h"

static const char *TAG = "gbhifi";

// ---- BT brownout loop breaker ----------------------------------------------
// Enabling the BT controller powers up the RF PHY and runs its calibration -- a
// fast current spike the boost converter must ride through. On a low battery
// (VIN near 2.4 V) the rail can dip below the brownout threshold, and because
// the BOD fires at the same point every boot, the board loops forever. Arm a
// magic word in RTC noinit RAM just before the radio comes up and clear it once
// BT init returns: if a boot then starts with reset reason BROWNOUT while the
// word is armed, the radio is what killed us. First such boot retries with an
// extra settle; after BT_BOD_MAX_TRIES consecutive kills the boot skips BT
// entirely, so the user gets chime + local audio instead of a reboot loop. RTC
// noinit survives the BOD's software reset but scrambles on a real power-off,
// so a battery change / power cycle re-arms BT automatically.
#define BT_BOD_MAGIC      0x42D0B000u   // upper 24 bits magic, low 8 = attempt count
#define BT_BOD_MAGIC_MASK 0xFFFFFF00u
#define BT_BOD_MAX_TRIES  2
static RTC_NOINIT_ATTR uint32_t s_bt_bod_guard;

// How many consecutive boots the BT controller enable has brownout-reset us,
// or 0 on a healthy boot. Reads the guard the *previous* boot armed, then
// clears it, so a brownout anywhere OUTSIDE the armed radio window (e.g. mid
// chime on a truly dead battery) isn't mis-attributed to the radio next boot.
// Call once, early in app_main.
static uint32_t bt_bod_kills(void)
{
    uint32_t kills = 0;
    if (esp_reset_reason() == ESP_RST_BROWNOUT &&
        (s_bt_bod_guard & BT_BOD_MAGIC_MASK) == BT_BOD_MAGIC) {
        kills = s_bt_bod_guard & 0xFFu;
    }
    s_bt_bod_guard = 0;
    return kills;
}

// Drain the ADC and feed the DAC one I2S block. Passed to es8388_init() so the
// I2S DMA stays serviced during I2C config; an unserviced DMA storms the CPU and
// trips the watchdog. Runs before audio_pipeline_start(), so nothing else touches
// I2S yet. It's also a raw RX->TX loopback, so the GBA's analog feed already
// passes to the DAC during codec config (inaudible until the amp is unmuted).
static void codec_service_i2s(void)
{
    static int32_t buf[256 * 2];
    size_t br = 0, bw = 0;
    if (i2s_codec_read(buf, sizeof(buf), &br, 50) == ESP_OK && br) {
        i2s_codec_write(buf, br, &bw, 50);
    }
}

// Hold-to-wake gate. The Connect/Pair button is tapped off the GBA R shoulder
// net and is also an EXT1 deep-sleep wake source, so a gameplay tap would
// otherwise wake the chip and spin up BT. On an EXT1 wake, require the button
// held for CONFIG_GBHIFI_WAKE_HOLD_S; a shorter press re-arms the wake sources and
// returns to deep sleep before any heavy init runs. PIN_PAM_SD stays RTC-held
// across the bounce so the speaker state is preserved.
static void gate_cp_wake(void)
{
    if (esp_sleep_get_wakeup_cause() != ESP_SLEEP_WAKEUP_EXT1) {
        return;  // cold boot or HP-detect (EXT0) wake
    }

    // Reclaim the button and HP pins from the RTC mux so we can read them.
    rtc_gpio_deinit(PIN_CP_BUTTON);
    rtc_gpio_deinit(PIN_HP_DETECT);
    gpio_config_t in = {
        .pin_bit_mask = (1ULL << PIN_CP_BUTTON) | (1ULL << PIN_HP_DETECT),
        .mode         = GPIO_MODE_INPUT,
        .pull_up_en   = GPIO_PULLUP_DISABLE,   // external 10k pull-ups
        .pull_down_en = GPIO_PULLDOWN_DISABLE,
        .intr_type    = GPIO_INTR_DISABLE,
    };
    ESP_ERROR_CHECK(gpio_config(&in));

    ESP_LOGI(TAG, "Connect/Pair wake: hold %d s to confirm (else back to sleep)",
             CONFIG_GBHIFI_WAKE_HOLD_S);
    for (int i = 0; i < CONFIG_GBHIFI_WAKE_HOLD_S * 50; i++) {
        if (gpio_get_level(PIN_CP_BUTTON) != 0) {  // released: game input
            ESP_LOGI(TAG, "button released after %d ms, back to sleep", i * 20);
            // Re-arm the same wake sources as DEEP_IDLE entry: ext0 on HP at the
            // opposite of its current level, ext1 on R LOW. Keep PIN_PAM_SD held.
            int hp_wake_level = (gpio_get_level(PIN_HP_DETECT) == 1) ? 0 : 1;
            ESP_ERROR_CHECK(esp_sleep_enable_ext0_wakeup(PIN_HP_DETECT,
                                                         hp_wake_level));
            ESP_ERROR_CHECK(esp_sleep_enable_ext1_wakeup(
                1ULL << PIN_CP_BUTTON, ESP_EXT1_WAKEUP_ALL_LOW));
            gpio_deep_sleep_hold_en();
            esp_deep_sleep_start();
        }
        vTaskDelay(pdMS_TO_TICKS(20));
    }
    ESP_LOGI(TAG, "button held, wake confirmed");
}

// Boot-time factory reset: if the Connect/Pair button (active LOW) is held from
// power-on for CONFIG_GBHIFI_FACTORY_RESET_S seconds, clear all bonded sinks.
// Releasing it before the deadline aborts. Runs after buttons_init and
// bt_a2d_init.
static void maybe_factory_reset(void)
{
    // Only on a true power cycle (GBA rail applied). A software reset that happens
    // to leave the button held must NOT count -- notably the Mode A -> B exit,
    // which reboots the instant the R-hold hits its threshold, with the button
    // still down. Without this gate the user, still holding R and waiting for the
    // "full mode" chime, would slide straight into the factory-reset countdown.
    if (esp_reset_reason() != ESP_RST_POWERON) {
        return;
    }
    if (gpio_get_level(PIN_CP_BUTTON) != 0) {
        return;  // button not held at boot
    }
    ESP_LOGW(TAG, "Connect/Pair held at boot, keep holding %d s for factory reset",
             CONFIG_GBHIFI_FACTORY_RESET_S);
    for (int i = 0; i < CONFIG_GBHIFI_FACTORY_RESET_S * 10; i++) {
        vTaskDelay(pdMS_TO_TICKS(100));
        if (gpio_get_level(PIN_CP_BUTTON) != 0) {
            ESP_LOGI(TAG, "button released, factory reset aborted");
            return;
        }
    }
    ESP_LOGW(TAG, "factory reset: clearing all bonds");
    bt_a2d_clear_bonds();
}

// Anti-brick confirmation for OTA. A freshly OTA'd image boots in PENDING_VERIFY;
// reaching this point means init completed without a panic, so mark the image
// good and cancel the pending rollback. A bad image that panics during init
// never gets here and the bootloader reverts on the next reset. The gate is
// "init completed" rather than a runtime milestone because the mod sits on the
// GBA switched rail and power-cycles constantly. Cable-flashed images boot
// UNDEFINED (rollback not armed), so this is a no-op for them.
static void ota_confirm_image_valid(void)
{
    const esp_partition_t *run = esp_ota_get_running_partition();
    esp_ota_img_states_t state;
    if (!run || esp_ota_get_state_partition(run, &state) != ESP_OK) return;
    if (state != ESP_OTA_IMG_PENDING_VERIFY) return;
    if (esp_ota_mark_app_valid_cancel_rollback() == ESP_OK) {
        ESP_LOGW(TAG, "OTA image on %s confirmed good, rollback cancelled", run->label);
    } else {
        ESP_LOGE(TAG, "esp_ota_mark_app_valid_cancel_rollback failed");
    }
}

void app_main(void)
{
    ESP_LOGI(TAG, "GameBoy HiFi v%s booting", esp_app_get_description()->version);

    // Read + clear the BT brownout guard first, before anything else can reset
    // us, so the count only ever reflects BODs inside the armed radio window.
    uint32_t bod_kills = bt_bod_kills();

    // Log the wake cause so the UART trace shows cold boot vs HP-plug (ext0) vs
    // R-button (ext1). The boot path is the same in all cases.
    esp_sleep_wakeup_cause_t cause = esp_sleep_get_wakeup_cause();
    switch (cause) {
    case ESP_SLEEP_WAKEUP_EXT0: {
        // EXT0 polarity is set at sleep entry to the opposite of the HP level,
        // so on wake the line is at the level that triggered it.
        int lvl = gpio_get_level(PIN_HP_DETECT);
        ESP_LOGI(TAG, "wake cause: EXT0 (HP %s, GPIO35 now %s)",
                 lvl ? "plug" : "unplug", lvl ? "HIGH" : "LOW");
        break;
    }
    case ESP_SLEEP_WAKEUP_EXT1: {
        uint64_t mask = esp_sleep_get_ext1_wakeup_status();
        ESP_LOGI(TAG, "wake cause: EXT1 (mask=0x%" PRIx64 ", R-button)", mask);
        break;
    }
    default:
        ESP_LOGI(TAG, "wake cause: cold boot (reason %d)", (int)cause);
        break;
    }

    // On an EXT1 wake, confirm an intentional hold before expensive init.
    gate_cp_wake();

    // Boot-mute the speaker amp. Its SD divider floats to "enabled", so without
    // this the amp runs before the DAC is clocking valid samples and pops. Cold
    // boot only: on a deep-sleep wake the pin is still RTC-held from before sleep,
    // and app_sm releases the hold and re-applies the mute policy.
    if (cause == ESP_SLEEP_WAKEUP_UNDEFINED) {
        gpio_config_t amp_sd = {
            .pin_bit_mask = 1ULL << PIN_PAM_SD,
            .mode         = GPIO_MODE_OUTPUT,
            .pull_up_en   = GPIO_PULLUP_DISABLE,
            .pull_down_en = GPIO_PULLDOWN_DISABLE,
            .intr_type    = GPIO_INTR_DISABLE,
        };
        ESP_ERROR_CHECK(gpio_config(&amp_sd));
        gpio_set_level(PIN_PAM_SD, 0);
    }

    // NVS holds the BT controller PHY calibration and the Bluedroid bond keys.
    esp_err_t nvs = nvs_flash_init();
    if (nvs == ESP_ERR_NVS_NO_FREE_PAGES || nvs == ESP_ERR_NVS_NEW_VERSION_FOUND) {
        ESP_ERROR_CHECK(nvs_flash_erase());
        nvs = nvs_flash_init();
    }
    ESP_ERROR_CHECK(nvs);

    // Bring up the I2S master bus first so the ES8388 sees MCLK before its I2C
    // config runs (the codec won't start its state machine without MCLK). Settle,
    // then configure over I2C. The production PCB's series-R + short MCLK routing
    // keep the writes clean, so no read-back verify pass is needed.
    ESP_ERROR_CHECK(i2s_codec_init());
    ESP_ERROR_CHECK(i2s_codec_start());
    vTaskDelay(pdMS_TO_TICKS(30));
    ESP_ERROR_CHECK(es8388_init(codec_service_i2s));

    // Codec configured; unmute the speaker amp now, before the DSP pipeline and
    // the deferred BT bring-up. The amp comes up on the audio path alone so the
    // Game Boy power-on chime plays the earliest possible moment; app_sm_start()
    // re-evaluates the amp against the real HP/state once it runs.
    app_sm_speaker_early_on();

    // DSP subsystem, ready before the pipeline task calls into it: settings holds
    // the parameter snapshot, fs mounts the clip store, sfx owns the cue feeder,
    // dsp seeds its coefficients from settings.
    ESP_ERROR_CHECK(settings_init());
    ESP_ERROR_CHECK(fs_init());
    ESP_ERROR_CHECK(sfx_init());

    // Seed the speaker volume from the wheel before dsp_init reads it, so the very
    // first audio block comes out at the wheel setting. Otherwise the wheel isn't
    // read until app_sm_start()'s poll (behind the BT hold-off below), and a
    // wheel-down user hears the stored default volume blare on every power-cycle.
    app_sm_prime_volume();

    ESP_ERROR_CHECK(dsp_init());

    // Seed the local-path EQ profile (Speaker vs Headphone) from the HP state
    // app_sm_speaker_early_on() already sampled, so the startup chime is voiced for
    // the live output from its first block. sm_task re-applies this on the live pin.
    dsp_set_hp_plugged(app_sm_hp_plugged());

    // Mod startup chime: play our own clean, complete chime clip over a muted live
    // passthrough, so the user hears one full chime instead of the truncated live
    // GBA chime (the codec/amp miss its first ~0.9 s of boot). dsp_begin_intro()
    // mutes the passthrough until the clip ends; sfx_trigger_clip() streams it.
    // Gated on sfx_enabled and startup_mode: with cues off, or the mode set to
    // STARTUP_OFF, this block does not run and the GBA's own chime plays through
    // untouched, missing its first ~0.9 s. STARTUP_ORIGINAL is that same chime
    // complete, as a clip. Both calls run before audio_pipeline_start(), i.e.
    // before the audio task exists, so the passthrough is muted from block one.
    // Voice the startup chime only on a genuine power cycle. Every other reset --
    // a Mode A/B change reboot (esp_restart, ESP_RST_SW), a watchdog, a brownout --
    // re-runs this boot path but should be silent: the user didn't power the console
    // on, and (for a mode-change reboot) the GBA never lost power, so the muted-
    // passthrough intro would just swallow the live game audio for no reason.
    gbhifi_settings_t boot_s;
    settings_get(&boot_s);
    bool power_on = (esp_reset_reason() == ESP_RST_POWERON);
    // Boot-mode decision (made once, gates BT init + the chime, handed to app_sm). A
    // Mode A boot keeps the radio off (battery mode + clean light sleep) and drops
    // STRAIGHT into Mode A -- no chime, no pause. A real power cycle consults the
    // persist flag; a mode-change reboot (SW reset) always lands in the saved mode.
    // Holding CP (R) at power-on forces Mode B -- the only Mode A boot escape.
    // Enable the button pad's input buffer before sampling: on a cold boot
    // nothing has configured it yet (gate_cp_wake only does on an EXT1 wake),
    // and an unconfigured input-only pad reads 0 -- a phantom "held" that
    // would divert the boot to Mode B. buttons_init() reconfigures the same
    // pad with interrupts later.
    rtc_gpio_deinit(PIN_CP_BUTTON);
    gpio_config_t cp = {
        .pin_bit_mask = 1ULL << PIN_CP_BUTTON,
        .mode         = GPIO_MODE_INPUT,
        .pull_up_en   = GPIO_PULLUP_DISABLE,   // external 10k pull-up
        .pull_down_en = GPIO_PULLDOWN_DISABLE,
        .intr_type    = GPIO_INTR_DISABLE,
    };
    ESP_ERROR_CHECK(gpio_config(&cp));
    bool cp_held = (gpio_get_level(PIN_CP_BUTTON) == 0);   // active LOW
    bool boot_mode_a = boot_s.mode_a && !cp_held &&
                       (!power_on || boot_s.boot_mode_a);
    ESP_LOGI(TAG, "boot-mode decision: mode_a=%d cp_held=%d reset=%d power_on=%d "
             "persist=%d -> %s", boot_s.mode_a, cp_held, esp_reset_reason(),
             power_on, boot_s.boot_mode_a, boot_mode_a ? "A" : "B");
    app_sm_set_boot_into_mode_a(boot_mode_a);
    if (boot_mode_a) {
        ESP_LOGI(TAG, "Mode A boot: skipping BT init + chime (BT-less battery mode)");
    }
    // Voice the startup chime only on a genuine power cycle into Mode B. Any other
    // reset (mode-change reboot, watchdog, brownout) re-runs this boot path silently.
    // NULL == STARTUP_OFF, which takes the cues-disabled path: no intro mute, no
    // clip, and the BT hold-off below is skipped since it exists only to keep the
    // radio off the chime.
    const char *startup_clip = settings_startup_clip(boot_s.startup_mode);
    bool use_mod_chime = boot_s.sfx_enabled && power_on && !boot_mode_a && startup_clip;
    if (use_mod_chime) {
        dsp_begin_intro();
        sfx_trigger_clip(startup_clip);
    }

    ESP_ERROR_CHECK(audio_pipeline_start());

    ESP_ERROR_CHECK(buttons_init());

    // Confirm a pending OTA image good as soon as the audio path is up, BEFORE the
    // BT delay below. The mod sits on the GBA's switched rail and power-cycles
    // constantly; gating this behind the ~3.5 s BT hold-off would let a power-cycle
    // during that window roll back an otherwise-good image.
    ota_confirm_image_valid();

    // A Mode A boot keeps the radio off entirely -- battery mode plus a clean,
    // conflict-free light-sleep loop -- so skip the whole BT bring-up below. Mode B
    // (and the Mode A escape window, which runs in Mode B local) bring the radio up.
    if (!boot_mode_a) {
    // Defer the Bluetooth controller + radio until CONFIG_GBHIFI_BT_START_DELAY_MS
    // after power-on, but ONLY when the startup chime is playing: the whole point of
    // the hold-off is to let the chime finish before the radio's inrush + PHY spike
    // land (they'd otherwise sag the boost rail under the chime's peak). A silent
    // reboot (mode change / watchdog) has no chime, so the delay is pure dead time
    // that shows up as an audible gap before Mode B audio fully comes up -- skip it
    // and bring BT + app_sm (final routing) up immediately.
    if (use_mod_chime) {
        int64_t elapsed_ms = esp_timer_get_time() / 1000;
        if (elapsed_ms < CONFIG_GBHIFI_BT_START_DELAY_MS) {
            vTaskDelay(pdMS_TO_TICKS(CONFIG_GBHIFI_BT_START_DELAY_MS - elapsed_ms));
        }
        // ...then keep holding until the startup chime has fully drained, so the
        // PHY-calibration spike doesn't land on the chime's final second. Capped so
        // a wedged cue can't block BT forever (chime is ~3.5 s, starts ~1 s in).
        for (int i = 0; sfx_cue_active() && i < 100; i++) {
            vTaskDelay(pdMS_TO_TICKS(50));
        }
    }

    if (bod_kills >= BT_BOD_MAX_TRIES) {
        // The radio brownout-reset the last BT_BOD_MAX_TRIES boots in a row: the
        // battery can't carry the PHY power-up. Come up local-only instead of
        // boot-looping; the bt_a2d_* API is guarded to no-op un-inited. A real
        // power cycle (battery change) scrambles RTC noinit and re-arms BT.
        ESP_LOGE(TAG, "BT radio brownout-reset the last %" PRIu32 " boots -- battery "
                 "too low for the radio, staying LOCAL-ONLY (power-cycle to retry)",
                 bod_kills);
    } else {
        if (bod_kills > 0) {
            // One strike: give the rail extra quiet time, then try once more.
            ESP_LOGW(TAG, "last boot brownout-reset during BT radio init "
                     "(attempt %" PRIu32 "/%d), retrying after settle",
                     bod_kills, BT_BOD_MAX_TRIES);
            vTaskDelay(pdMS_TO_TICKS(2000));
        }

        // Park the speaker amp for the radio bring-up window so the PHY spike is
        // the only load transient on the boost; the chime is done (waited out
        // above), so at most a sub-second gap in the live passthrough.
        app_sm_amp_radio_quiet(true);
        vTaskDelay(pdMS_TO_TICKS(250));   // let the amp/rail settle before the spike

        s_bt_bod_guard = BT_BOD_MAGIC | (bod_kills + 1);
        ESP_ERROR_CHECK(bt_a2d_init());

#if CONFIG_GBHIFI_BLE_CONFIG
        // BLE GATT config server alongside the A2DP source (controller in BTDM dual
        // mode). Comes up after bt_a2d_init() since Bluedroid is enabled there.
        ESP_ERROR_CHECK(ble_config_init());
#endif
        s_bt_bod_guard = 0;   // radio survived: disarm the loop breaker

        app_sm_amp_radio_quiet(false);
    }
    }   // end if (!boot_mode_a)

    // Factory reset before the state machine starts: Connect/Pair held from
    // power-on clears all bonds, dropping the next boot into pairing.
    maybe_factory_reset();

    ESP_ERROR_CHECK(app_sm_start());

    // UART REPL control surface, started last. The web UI (BLE config) drives the
    // same settings_* API. Needs an interactive serial monitor for input.
    ESP_ERROR_CHECK(console_start());

    while (1) {
        vTaskDelay(pdMS_TO_TICKS(60000));
        ESP_LOGI(TAG, "alive (free heap: %" PRIu32 " B, min ever: %" PRIu32 " B)",
                 esp_get_free_heap_size(), esp_get_minimum_free_heap_size());
        app_sm_batt_check();
    }
}

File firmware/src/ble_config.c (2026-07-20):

#include "ble_config.h"

#include "sdkconfig.h"

#if CONFIG_GBHIFI_BLE_CONFIG

#include <stdio.h>
#include <string.h>
#include <unistd.h>

#include "esp_bt.h"
#include "esp_gap_ble_api.h"
#include "esp_gatts_api.h"
#include "esp_gatt_common_api.h"
#include "esp_log.h"
#include "esp_timer.h"
#include "esp_system.h"

#include "esp_ota_ops.h"     // OTA: esp_ota_begin/write/end, partition select
#include "esp_app_desc.h"    // OTA: running app version for GET_INFO
#include "esp_rom_crc.h"     // OTA: incremental crc32 sanity check

#include "freertos/FreeRTOS.h"
#include "freertos/task.h"
#include "freertos/queue.h"
#include "freertos/stream_buffer.h"

#include "esp_console.h"     // BLE console: esp_console_run() reuses the UART cmd table

#include <stdarg.h>
#include <stdlib.h>

#include "fs.h"
#include "settings.h"
#include "sfx.h"
#include "audio_pipeline.h"   // spectrum tap for the BLE web visualizer
#include "app_sm.h"           // app_sm_hp_plugged(): distinguishes speaker vs headphone for the spectrum source byte

static const char *TAG = "ble_cfg";

#define BLE_DEVICE_NAME   "GameBoy HiFi Setup"
#define BLE_APP_ID        0x42
#define ACTION_MAX_LEN    40         // opcode + clip-name room

// ---- GATT schema ----------------------------------------------------------
// Custom 128-bit UUIDs, stored LSB-first as Bluedroid expects.
//   service:  5a4d0000-1f2e-4c6b-9a8f-0102030405aa
//   settings: 5a4d0001-...   (R/W/Notify, packed gbhifi_settings_t mirror)
//   action:   5a4d0002-...   (Write: save / chime / play)
static const uint8_t SVC_UUID128[16] = {
    0xaa, 0x05, 0x04, 0x03, 0x02, 0x01, 0x8f, 0x9a,
    0x6b, 0x4c, 0x2e, 0x1f, 0x00, 0x00, 0x4d, 0x5a,
};
static const uint8_t SETTINGS_UUID128[16] = {
    0xaa, 0x05, 0x04, 0x03, 0x02, 0x01, 0x8f, 0x9a,
    0x6b, 0x4c, 0x2e, 0x1f, 0x01, 0x00, 0x4d, 0x5a,
};
static const uint8_t ACTION_UUID128[16] = {
    0xaa, 0x05, 0x04, 0x03, 0x02, 0x01, 0x8f, 0x9a,
    0x6b, 0x4c, 0x2e, 0x1f, 0x02, 0x00, 0x4d, 0x5a,
};
//   otactl:  5a4d0003-...   (Write + Notify: OTA control / status)
//   otadata: 5a4d0004-...   (Write-no-response: raw firmware chunks)
static const uint8_t OTACTL_UUID128[16] = {
    0xaa, 0x05, 0x04, 0x03, 0x02, 0x01, 0x8f, 0x9a,
    0x6b, 0x4c, 0x2e, 0x1f, 0x03, 0x00, 0x4d, 0x5a,
};
static const uint8_t OTADATA_UUID128[16] = {
    0xaa, 0x05, 0x04, 0x03, 0x02, 0x01, 0x8f, 0x9a,
    0x6b, 0x4c, 0x2e, 0x1f, 0x04, 0x00, 0x4d, 0x5a,
};
//   log:     5a4d0005-...   (Notify: device -> client ESP_LOG / console stream)
//   cmd:     5a4d0006-...   (Write / Write-NR: client -> device console line)
static const uint8_t LOG_UUID128[16] = {
    0xaa, 0x05, 0x04, 0x03, 0x02, 0x01, 0x8f, 0x9a,
    0x6b, 0x4c, 0x2e, 0x1f, 0x05, 0x00, 0x4d, 0x5a,
};
static const uint8_t CMD_UUID128[16] = {
    0xaa, 0x05, 0x04, 0x03, 0x02, 0x01, 0x8f, 0x9a,
    0x6b, 0x4c, 0x2e, 0x1f, 0x06, 0x00, 0x4d, 0x5a,
};
//   spec:    5a4d0007-...   (Notify: stereo live audio spectrum, L bands + R bands)
static const uint8_t SPEC_UUID128[16] = {
    0xaa, 0x05, 0x04, 0x03, 0x02, 0x01, 0x8f, 0x9a,
    0x6b, 0x4c, 0x2e, 0x1f, 0x07, 0x00, 0x4d, 0x5a,
};
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

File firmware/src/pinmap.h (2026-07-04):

#pragma once

// Single source of truth for all pin assignments. Do not hard-code GPIO
// numbers anywhere else.
//
// Board: ESP32-PICO-MINI-02 with the ES8388 codec on a full-duplex I2S master
// bus plus I2C control.

// ----- I2S0: full-duplex master to the ES8388 -----
// The ESP32 masters the bus and generates MCLK, BCLK, and LRCK; the ES8388 is
// the I2S slave. MCLK comes off the APLL on GPIO0 (the only free MCLK-capable
// pin; GPIO1/3 are the console UART) and reaches the codec through a series
// resistor. DIN/DOUT are named from the ESP32 side: our DOUT drives the codec
// DAC input (DSDIN), our DIN reads the codec ADC output (ASDOUT).
#define PIN_I2S_MCLK     0   // ES8388 MCLK (APLL)
#define PIN_I2S_BCK     25   // shared bit clock
#define PIN_I2S_LRCK    26   // shared word/LR clock
#define PIN_I2S_DOUT    27   // to ES8388 DSDIN (DAC playback)
#define PIN_I2S_DIN     14   // from ES8388 ASDOUT (ADC capture)

// ----- I2C0: ES8388 control (address 0x10) -----
#define PIN_I2C_SDA     21
#define PIN_I2C_SCL     22

// ----- Analog input: GBA volume wheel (VR2 wiper) -----
// Read on ADC1; GPIO39 is input-only. In Mode B the wheel sets the DSP digital
// volume; in Mode A it sets the ES8388 analog-bypass volume over I2C. The wheel
// is powered from VBAT, so its reading is battery-referenced (see PIN_VBAT_ADC).
#define PIN_VOL_ADC     39

// ----- Analog input: battery-rail sense -----
// VBAT (the GBA battery rail feeding the U3 boost) through an R20/R21 = 100k/100k
// divider into ADC1_CH0 (GPIO36, input-only). VBAT = 2 * V(PIN_VBAT_ADC). Shares
// the ADC1 oneshot unit with the volume wheel.
#define PIN_VBAT_ADC    36

// ----- Control outputs -----
// External mono speaker-amp shutdown/mute (active HIGH = amp enabled).
// app_sm asserts mute when BT is STREAMING or wired HP is plugged.
#define PIN_PAM_SD       4

// ----- Wake-source inputs (RTC GPIOs, input-only, external 10k pull-ups) -----
// Connect/Pair button: the mod's control input (connect / pair, deep-sleep
// wake, boot-time factory reset). Tapped off the GBA R shoulder net.
#define PIN_CP_BUTTON   34   // LOW = pressed (idle pulled HIGH by 10k)

// HP-detect. Polarity is inverted vs a typical detect line: the GBA's internal
// headphone-jack switch grounds this sense line when nothing is plugged in.
// With the external 10k pull-up to 3.3 V, the ESP32 reads HIGH = plugged,
// LOW = unplugged.
#define PIN_HP_DETECT   35   // HIGH = headphones plugged, LOW = unplugged

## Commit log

2026-06-22 Initial release: GameBoy HiFi Audio
    Bluetooth A2DP audio mod for the Game Boy Advance. ESP32 + ES8388 firmware (shared across board models), the AGB hardware (main board and flex), the Web Bluetooth config UI, and user/builder/firmware docs.
    [agb-hifi-audio-fpc.kicad_sch, agb-hifi-audio-fpc.stl, agb-hifi-audio-pcb.kicad_sch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]
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2026-06-23 bom(agb): switch passives to JLCPCB basic parts
    Replace extended LCSC parts with basic-library equivalents across the
    audio PCB to reduce JLCPCB assembly part-fee count (now 16 basic / 10
    extended, up from 2 basic). All swaps preserve footprint and value; the
    only spec changes are voltage upgrades (1uF 16->25V, 4.7uF 6.3->10V).
    316k, 10nF C0G, 220uF tantalum, ferrite, inductor and the ICs have no
    basic equivalent and remain extended. Stale DigiKey refs cleared on the
    swapped parts. Schematic, PCB and bom.csv kept in sync.
    [agb-hifi-audio-pcb.kicad_sch, bom.csv]
2026-06-23 fpc(agb): define connector-tail stiffener (JLC bottom 0.2mm)
    Add the bottom-side polyimide stiffener outline under the FH12 gold
    fingers on a renamed User.3 (JLC_Stiffener_Bottom_0.2mm) layer, ending
    before the 180-degree fold region, plus a fab note. Mark the connector
    reference footprint DNP / exclude from BOM and POS.
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2026-07-04 docs: move v1.0 bring-up findings + antenna notes to PROTOTYPE-V1.0.md
    Keep the main hardware and firmware guides clean of prototype troubleshooting.
    New docs/PROTOTYPE-V1.0.md collects the bench-rig setup (FT232H/ftdi_sio udev
    fix, battery-rail power vs the Tag-Connect cable), the confirmed U4 PAM8302A
    IN- DC-ground defect (2.7 V output offset, ~300 mA, self-heating; Rev B fix is
    to AC-couple IN-), and the antenna MHF III / W.FL finding relocated out of
    HARDWARE.md (which now carries a short pointer).
2026-07-04 firmware(agb): tune codec output levels (speaker -10.5 dB, HP -15 dB)
    Default output driver levels were lopsided on the first board: the speaker
    line-out sat at 0 dB feeding the PAM8302A's ~+23.5 dB fixed gain, overdriving
    the 8 ohm speaker, while the headphone amp at -24 dB was too quiet. Tuned by ear
    on the bench:
    - LOUT2/ROUT2 (speaker line-out): 0x1e (0 dB) -> 0x17 (-10.5 dB)
    - LOUT1/ROUT1 (headphone amp): 0x0e (-24 dB) -> 0x14 (-15 dB)
    Updated in both es8388_init() and the boot-verify table (s_critical_cfg), or the
    verify pass would re-fix them to the old values.
    [es8388.c]
2026-07-04 docs(agb): record U4 IN- bodge validation in prototype log
    The IN- coupling-cap fix was applied to the first board and confirmed: SPK+/SPK-
    DC offset dropped from 2.7 V to 0 V, U4 runs cool, no brownout/cook cycle.
2026-07-04 firmware(agb): battery reader, ratiometric VOL wheel, low-batt latch
    Read VBAT via the R20/R21 = 100k/100k sense divider on ADC1_CH0 (shares the ADC1
    oneshot unit with the VOL wheel; adds an adc_cali line-fit handle for raw->mV).
    VBAT = 2 * sense.
    - `batt` console command and a per-60s heartbeat log of VBAT and rough %.
    - The VOL wheel is now battery-referenced: each raw reading is normalised to
    VBAT_REF_MV so the fixed VOL_RAW_MIN/MAX window holds as VBAT droops (the GBA
    volume pot is powered from VBAT). Falls back to raw-only if the sense fails.
    - Low-battery latch with hysteresis (warn under 2500 mV, clear over 2650 mV),
    polled from the heartbeat.
    Validated on the bench against a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
    [app_sm.c, app_sm.h, console.c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]
2026-07-04 firmware(agb): match Mode A volume ceilings to the tuned Mode B levels
    The Mode A analog-volume ceilings (ES8388_LINE_VOL_MAX/HP_VOL_MAX) were stale
    relative to the tuned Mode B driver levels: line out 0x21 (+4.5 dB) and HP 0x0e
    (-24 dB) vs Mode B's 0x17 (-10.5 dB) / 0x14 (-15 dB). At full VOL wheel Mode A
    hit those ceilings, so a B->A switch jumped the loudness and drove the speaker
    into the PAM8302A's clipping.
    Make the two ceilings the single source of truth for the tuned levels: used by
    es8388_init() and the verify table as the fixed Mode B levels, and by
    es8388_set_output_volume() as the Mode A ceilings, so the modes stay in lockstep.
    Verified on the bench: Mode A now level-matches Mod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
    [es8388.c]
2026-07-04 docs(agb): document Mode A/B transition findings in prototype log
    Bidirectional Mode A/B transitions tested clean (B->A via console, A->B via
    R-hold; ~40 vs ~80 mA at the board). Records the two findings: the Mode A
    speaker-level overdrive (now fixed) and that the console can't exit Mode A over
    serial (by design, since the ESP32 is in light sleep and the UART is not a wake
    source).
2026-07-05 tools(serial_proxy): open the port without the DTR glitch on (re)attach
    Constructing serial.Serial() with a port opens immediately and asserts DTR, which
    the board's DTR/RTS -> EN auto-reset circuit turns into a spurious chip reset on
    every (re)attach. Build the port unopened and force dtr/rts low before open() so
    reopens (e.g. when a flaky cable re-enumerates) no longer reboot the chip.
2026-07-05 firmware(agb): GBA noise investigation + tunable reduction
    Tools to measure the GBA audio noise floor, and a tunable DSP stage to reduce it.
    Measurement:
    - `radio off`/`on` gates BT inquiry/paging + BLE advertising for a clean GBA-only
    capture without RF coupling.
    - `wavedump [n]` captures raw ADC samples on demand (no level arming, so it grabs
    the quiet floor) and dumps CSV over UART.
    - tools/plot_wavedump.py parses it: RMS/peak, spectral floor, dominant tones, and a
    gate-vs-notch-vs-HPF recommendation.
    Reduction (Mode B, on the captured signal before the EQ; `nr` command, NVS-persisted,
    Kconfig defaults):
    - HPF / LPF / notch biquads for hum / hiss / a discrete tone.
    - A downward ex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
    [app_sm.c, audio_pipeline.c, ble_config.c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]
2026-07-05 docs(agb): noise-floor findings + serial-cable reboot gotcha in prototype log
    Record the noise characterisation (21.4 kHz PWM-carrier alias, 172 Hz hum), the DSP
    reduction stage + baked defaults, the Rev B items (anti-alias filter, differential
    audio tap), and the bus-powered-FTDI VCC-to-+3V3 reboot loop.
2026-07-05 firmware(agb): boot the Game Boy chime cleanly + faster audio bring-up
    The mod boots on the GBA's switched rail, so the power-on chime is the first
    thing heard every power-cycle. Previously the mod (a) beeped its connect/pairing
    cue over the chime and (b) clipped the chime's first ~2 s behind boot latency.
    Boot order reworked for audio-first (see docs/FIRMWARE.md "Init order"):
    - Unmute the speaker amp right after es8388_init(), HP-aware (speaker only when
    no headphones are plugged), instead of inside app_sm_start() behind BT init.
    - Drop the codec read-back verify pass: a breadboard-era artifact; the PCB's
    series-R + short MCLK routing keep the I2C config writes clean. First audio
    no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
    [app_sm.c, app_sm.h, dsp.c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]
2026-07-05 firmware(agb): manual BT connect-on-boot policy + pairing->Mode A fix
    Add an auto_connect setting (default off) so the device no longer starts
    paging/pairing on its own. With it off the radio comes up idle and rests
    in LOCAL_ONLY; BT only starts on a Connect/Pair (R) hold. Persisted in
    NVS (settings v9), configurable via the console `autoconnect on|off`
    command and shown in `get`; Kconfig seeds the first-boot default.
    Gate every automatic entry into the reconnect campaign centrally in the
    ST_STANDBY entry, so the setting is honored consistently (boot, Mode A
    exit, pairing-session timeout), not just at boot. A dropped live link
    (CONNECTED_IDLE/STREAMING -> STANDBY) is exempt and still auto-r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
    [app_sm.c, bt_a2d.c, console.c]
2026-07-05 docs(agb): manual reflects manual BT connect-on-boot
    The mod no longer turns Bluetooth on by itself at power-on: it starts
    quietly on the speaker/wired jack and waits for a hold-R-to-first-chime to
    reconnect saved headphones. Document that, note that a mid-stream dropout
    still reconnects on its own, that auto-reconnect-at-power-on is an optional
    saved setting (off by default), and that mode switching works even while
    searching. Add a troubleshooting entry for "does not reconnect on power-on".
2026-07-06 hardware(agb): rev B board changes — built-in antenna, U4 IN- AC-couple, drop R5/R6
    - U1: ESP32-PICO-MINI-02U-N8R2 (external MHF III) -> -02-N8R2 (built-in PCB
    antenna) to remove the MHF III antenna sourcing problem; new footprint
    MODULE_ESP32-PICO-MINI-02 + 3D STEP, plus the module antenna keepout.
    - U4 (PAM8302A): add C27 1uF AC-coupling on IN- to GND (value-matched to C19
    on IN+). Fixes the 2.7 V SPK+/SPK- DC offset, ~300 mA draw and self-heating
    — the bench-validated bodge from PROTOTYPE-V1.0.
    - Remove R5/R6 (10k DNP hedge resistors on the codec output nets), confirmed
    unneeded on the bench.
    - docs: correct the U4 gain claim (R7/R8 15k already set ~12.6 dB, not 23.5 dB
    ma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
    [agb-hifi-audio-pcb.kicad_sch]
2026-07-07 hardware(agb): schematic as BOM source of truth; docs + DigiKey sync
    - Populate the DigiKey field on all 41 sourced parts in the main-board
    schematic and PCB (LCSC/DigiKey dual-source; ES8388 has no DigiKey line).
    - Delete hardware/agb/bom.csv; the KiCad schematic is now the single BOM
    source of truth. Speaker accessory options move to AGB-INSTALL.md.
    - HARDWARE.md: add the full inline BOM (passives by value, no MPNs); fix the
    stale antenna section (built-in -02 PCB antenna, not -02U/MHF III); correct
    the false 'ESP32 module is castellated' note; U1 -> -02; drop bom.csv link.
    - README: schematic carries the BOM.
    [agb-hifi-audio-pcb.kicad_sch, bom.csv]
2026-07-09 firmware(agb): noise-reduce the BT/A2DP path + wheel drives BT volume
    The A2DP source fed the raw GBA capture floor into the SBC encoder, which
    rendered the low-level hum/hiss as a distinct digital hash on the sink -- the
    BT path (dsp_process_bt) skipped the `nr` HPF/gate the local path runs. Run the
    shared nr filters + expander on the BT stream too, and add a BT-specific
    hard-mute at -30 dBFS (BT_MUTE_THRESH_DB): during A2DP streaming the radio's
    conducted TX transients lift the per-block floor peak up to ~the local -42 gate
    threshold, so the shared silence detector never commits on BT (it works for
    local, which plays with the radio idle) -- the BT mute needs its own threshold
    clear of the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
    [app_sm.c, audio_pipeline.c, dsp.c]
2026-07-09 firmware(agb): bound A2DP buffer latency + fix connect-time overflow
    The pipeline pushed PCM into the 12 KB A2DP stream buffer unconditionally, so
    while idle/connecting it pre-filled to full and handed the SBC encoder a full
    (~70 ms) buffer at connect that overflowed and dropped -- garbled audio for a
    second or two. And with no rate matching the 44.1 kHz producer slowly outran the
    sink, drifting the fill toward overflow over minutes (latency creeping to ~58 ms).
    - Gate the producer push on the A2DP media state (audio_pipeline_set_bt_streaming,
    set from bt_a2d at MEDIA_STARTED / SUSPEND / disconnect); empty the buffer on the
    streaming->idle edge (the consumer is idle then, so no reset ra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
    [audio_pipeline.c, bt_a2d.c]
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2026-07-11 firmware(agb): survive low-battery boot; fix pairing CoD filter; bt console cmd
    At VIN ~2.4 V the board brownout-looped forever at BT controller enable:
    the RF PHY's boot-time partial-calibration TX burst is the largest, fastest
    load step of the whole boot, and it landed while the startup chime was still
    playing. At low VIN the boost's transient floor (VIN minus a diode drop)
    sits below the ESP32 BOD threshold, so a deep dip resets the chip; at 3.2 V
    the floor is above it, which is why this never showed on a healthy battery.
    - CONFIG_ESP_PHY_RF_CAL_NONE: skip the boot-time cal burst, run from
    NVS-stored cal data (the decisive change; sequencing alone didn't survive)
    - hold BT until the ch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
    [app_sm.c, app_sm.h, bt_a2d.c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]
2026-07-12 firmware(agb): blacklist failing sinks per pairing session
    A nearby A/V device that passes the class-of-device sink filter but
    refuses the A2DP source role (e.g. a TV sharing a speaker's exact CoD
    0x280424) would win every inquiry, get paged, fail OPEN with status 2,
    and then be re-matched on the immediate re-scan — an endless page/fail
    loop that starves the sink the user actually wants and floods the
    audio/log path with churn.
    Track a per-session blacklist of BDAs that fail to open A2DP (a failed
    page is distinguished from a real post-connect drop by still being in
    LINK_PAGING) and skip them in handle_inquiry_result without cancelling
    discovery, so a different working sink can still answ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
    [app_sm.c, bt_a2d.c]
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2026-07-12 firmware+web(agb): replace unplug-to-B with persist-Mode-A setting
    Drop the "switch to Full mode on HP unplug" (unplug_to_b) setting, which
    had little practical value, and repurpose the settings slot + web toggle
    to "persist Mode A across power cycles" (boot_mode_a, default on). On an
    HP unplug in Mode A the device now simply stays in Mode A.
    Bumps the NVS settings version (9 -> 10), so stored settings reset to
    defaults on first boot of this image. Web checkbox relabeled to "Stay in
    Battery saver after power off"; BLE config byte [15] now carries
    boot_mode_a. Mode A/B itself is read-only over BLE (unchanged).
    [ble_config.c]
2026-07-12 firmware(agb): reboot-based Mode A/B switching, BT-less Mode A
    Mode changes now reboot into the target mode instead of switching in
    place: app_sm_switch_mode() persists the mode and esp_restart()s, and a
    Mode A boot skips BT controller init entirely. This makes Mode A both
    reliable and lower power -- with no BT controller there's nothing to
    conflict with the hand-rolled light-sleep loop (the RTCWDT resets that
    hit the in-place STREAMING->Mode A path and console-in-Mode-A are gone),
    and the radio's idle draw is removed (~254 mA vs ~277 mA in Mode B at
    matched backlight).
    - Boot drops straight into Mode A (no window); holding CP (R) at
    power-on forces Mode B -- the only boot escape.
    - Start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
    [app_sm.c, app_sm.h, bt_a2d.c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]
2026-07-13 firmware(agb): runtime BLE/BT bench knobs on the radio console command
    Split 'radio' into independent sub-verbs for noise isolation work:
    radio ble|bt on|off, radio bleint <ms> (advertising interval override),
    radio blepwr <dBm> (BLE TX power). Used to fingerprint the BLE-advertising
    click coupling into the codec analog outputs; none persist across reboot.
    [ble_config.c, console.c]
2026-07-13 hardware(agb): rev 1.1 — codec analog LDO, rail bulk, BOD margin
    BT radio-wake bursts on the shared 3V3 boost rail were bench-localized to
    analog injection in both output stages (ES8388 DAC/mixer via AVDD for HP,
    PAM8302 stage for speaker); TX power/interval don't fix it, supply
    isolation does. Changes:
    - U5 LP5907MFX-3.0 low-noise LDO: +3V3 -> FB1 -> AVDD_IN -> U5 -> AVDD;
    C6/C7 become LDO input reservoir, new C31 1u output cap
    - 22u line swapped to CL21A226MAQNNNE 25V 0805 (JLC basic) at C1/C2 plus
    new C32 (ESP32 3V3), C33 (PAM VDD), C34 (VOUT), C35 (VIN) — BOD margin
    items from the 1.0 bring-up doc, ~20uF -> ~60uF effective rail bulk
    - L1 kept: INPAQ WIP252012P-R47ML Isat 4.95A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
    [agb-hifi-audio-pcb.kicad_sch]
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2026-07-13 docs: public-readiness pass; add install alternative and battery-life section
    Move prototype/bring-up notes, war stories, and personal-tool workflow docs
    out of the tracked tree into a gitignored history/ (PROTOTYPE-V1.0.md,
    README-ble-dev.md, ble-proxy.json); gitignore hardware/agb/references/.
    Trim docs and firmware comments to current state (what over why): drop rev
    1.0/1.1 narrative and prototype cross-references from HARDWARE.md/FIRMWARE.md,
    replace the personal serial-proxy skill references with standard PlatformIO +
    esptool guidance in FIRMWARE.md/AGENTS.md, and generalize the bench-tool paths
    in tools/bringup.py.
    Add a battery-life section to MANUAL.md and an alternative R30/R31 au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
    [main.c]
2026-07-13 firmware(agb): fix Mode A not surviving a power cycle
    The boot-mode decision sampled the Connect/Pair pad (the hold-R-to-escape
    check) before anything had enabled its input buffer on a cold boot. ESP32
    input-only pads power up with the buffer disabled and read 0, so every
    power-on saw a phantom held R and diverted to Mode B; boot_mode_a=on never
    worked across a real power cycle. Mode-change reboots (SW reset) kept the
    prior session's pad config, which is why switching into Mode A appeared
    fine.
    Configure the pad as an input before the sample, and log the decision
    inputs (mode_a, cp_held, reset reason, persist flag) at boot.
    Bench-verified both ways: power-on in Mode A stays in Mode A; Mode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
    [main.c]
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2026-07-18 firmware(agb): don't erase the whole OTA slot up front
    esp_ota_begin() was passed the image size, which erases the entire
    target slot before returning (~4 s on a slot holding the old image)
    while the radio is starved. The 8 s supervision-timeout widening plus a
    500 ms grace delay papered over it, but only if the central honors the
    requested parameters in time -- BlueZ's 720 ms default is exactly the
    case that bites (same bug fixed in bluetooth-nes-advantage 0b6d594).
    Pass OTA_WITH_SEQUENTIAL_WRITES instead: BEGIN returns in ~40 ms and
    each sector erases inside esp_ota_write(), interleaved with the chunks
    the windowed protocol already delivers in sequence. The grace delay is
    gone; the widene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
    [app_sm.c, ble_config.c]
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2026-07-19 firmware(agb): key the noise gate on block RMS, wake the amp for cues
    The BLE TX clicks measure -37..-45 dBFS peak in the ADC capture --
    above the -42 dBFS gate threshold -- so the peak-keyed expander opened
    for every click and each one reset the amp-mute hold, keeping the
    speaker awake to play them. Their block RMS is only -45..-55 dBFS
    (sub-ms transients carry no energy) while real program holds RMS near
    its peak, so RMS keying gates the clicks and lets the amp-mute engage;
    an idle web-config page now goes fully silent. Same change on the BT
    gate. While the mute holds, the program is also driven to digital zero
    so headphones (no shutdown pin) get the same silence.
    The amp-mute now also co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
    [dsp.c]
2026-07-19 firmware(agb): make the startup sound configurable
    startup_mode picks the boot chime: the Switch/NSO version (default), the
    original GBA chime, a user-supplied clip, or off. Off leaves the live
    passthrough alone, which starts ~0.9 s late because the codec and amp are
    still coming up; ORIGINAL is that same chime complete. All three clips ship
    in the filesystem image, superseding startup.gsfx.
    The settings wire grows 28 -> 64 bytes and becomes append-only and
    length-tolerant, so later fields are not breaking changes. Byte 29 reports
    whether the custom slot is filled. NVS version 11 resets stored settings.
    The web page converts a dropped MP3/M4A/WAV/OGG/FLAC to GSFX in the browser
    (decode at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
    [ble_config.c, console.c, main.c]
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2026-07-19 firmware(agb): per-chemistry battery meter, low-power chimes, tunable BT mute
    Battery meter
    - settings.batt_chem (alkaline | nimh | lipo-reg); chemistry is the only
    user knob. Per-chemistry discharge model + fixed nominal ESR live in
    app_sm.c (BATT_MODELS): a universal 4-level band (Full/Good/Low/Critical),
    with a real percent only for alkaline -- NiMH/LiPo are banded (a percent
    would sit at ~50% through the whole plateau then collapse). Replaces the
    hard-coded linear 2xAA map.
    - Load comp adds back the mode's *variable* current delta * a fixed nominal
    series R (batt_var_current_ma), so the level doesn't step when the mode
    changes; the ~constant GBA/IPS floor is absorbed into t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
    [app_sm.c, app_sm.h, ble_config.c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]
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2026-07-20 firmware(agb): Mode A→B return chime, factory-reset gate, 3s exit hold
    Bump to 1.1.0.
    - Restore the "full mode" return chime on Mode A→B. The mode switch became an
    esp_restart(), which stranded the old in-loop cue as unreachable dead code;
    carry the cue across the reboot via an RTC_NOINIT flag armed on switch-to-B
    and consumed on the Mode B boot (gated on ESP_RST_SW).
    - Gate the boot-time factory reset on a true power cycle (ESP_RST_POWERON). The
    Mode A exit fires at the hold threshold and reboots with R still held, so
    without this the still-held button slid into the factory-reset countdown.
    - Cut the Mode A exit-hold default from 9s to 3s so the user isn't holding
    blind for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
    [app_sm.c, main.c]
2026-07-20 firmware(agb): OTA rollback to the previous firmware slot
    New OTACTL opcode (0x07) boots the inactive slot, applying the same identity
    gate as an OTA finish so an erased, foreign, or invalidated image is refused.
    GET_INFO now also reports the previous image's version and build date so the UI
    can label or hide the control. The web Firmware card gains a "Roll back to vX"
    button, hidden when there is no valid previous image, with a confirm dialog
    warning that an older settings schema may reset preferences (BT bonds survive).
    [ble_config.c]
2026-07-22 hardware(agb): reroute mod PCB for the smaller shell fit; trim + reinforce FPC lead
    Mod PCB: full reroute after narrowing the outline 28.5mm -> 25.35mm to fit the
    shell. U2 (codec) moved and rotated 90deg with NT1 following; fiducials dropped
    (sub-70x70 boards ride JLCPCB rails, which carry their own). Layout review
    verified clean: DRC 0 unconnected, antenna keep-outs intact with the module
    antenna overhanging the edge, zones refilled, power widths unchanged.
    FPC: lead tip trimmed 1.25mm (y128 -> y126.75) to clear the volume wheel --
    1.6mm is the geometric max without moving the J5 finger pattern, and the
    shorter setback lands closer to the Hirose copper-to-tip recommendation.
    Stiffener pul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
    [agb-hifi-audio-fpc.stl]
2026-07-22 hardware(agb): switch FPC1 to JUSHUO AFC07-S12ECA-00
    The Hirose FH12A-12S-0.5SH(55) is out of stock at JLCPCB/LCSC (2 pcs left),
    which blocks assembly. Replace it with the JUSHUO AFC07-S12ECA-00 (LCSC
    C262585, ~19k stock): same 12-pos 0.5mm top-contact ZIF at the same 2.0mm
    height, and the flex tail meets its mating spec (0.3mm thickness, 3.5mm
    exposure vs 3.0 minimum, 6.5mm width).
    Not a drop-in: the AFC07 fitting nails sit 2.26mm from the pin row vs the
    Hirose's 3.25mm, on top of the old VOL/SW/PAIR and VBAT fanout channel, so
    those nets are rerouted around the new nail lands. Pin row and net order are
    unchanged; the flex geometry is untouched. DRC is clean (0 unconnected, no
    live violati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
    [agb-hifi-audio-pcb.kicad_sch]
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2026-07-22 hardware(agb): trim FPC lead a further 1.25 mm (2.5 mm total)
    Shorten the connector lead to y125.5 (from y126.75), reaching the 2.5 mm total
    trim that clears the volume wheel with margin. This pass moves the J5 finger
    pattern up 1.2 mm with the edge (origin y126.4 -> y125.2, pad tips y125.2,
    0.3 mm from the board edge), since the first 1.25 mm pass had already reached
    the limit of a length-only cut. Stiffener follows flush at y120.675-125.5
    (4.825 mm coverage, above the 4.5 mm Hirose minimum). Flex is now 23.1 x
    34.8 mm. DRC clean; JLCPCB production files re-exported.
    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
    [agb-hifi-audio-fpc.stl]
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
